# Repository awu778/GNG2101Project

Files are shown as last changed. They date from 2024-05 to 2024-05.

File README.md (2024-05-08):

# Helpo
This repository contains the design for the Helpo Keyboard. While there will be sales of the keyboard
in the future, this repository provides the files necessary for anyone to create a copy of the board for
personal use.
# Description
Photoshops landscape is large, confusing, and difficult to learn for disabled artists. Helpo is a photoshop assistant designed to increase the digital art app's accessibility through interactive tool select feedback, voice commands, and a physical tool keyboard. The project could be built for less than $40. Groups trying to replicate this project should watch out for the scope of the project; it's very easy to forget about one area when progress is being made in another. Possible steps forward include: improving the colour picker design while keeping it accessible (no colour cloud), adding the option for line smoothing, a cleaner integration into the photoshop interface, the ability to select specific brush sizes and colours from Helpo directly, and the ability to select favourite tools or brushes.

If you want to use this software, please download the Helpo_8.zip and Helpo.xml files. Unzip the .zip file and run the installer. To load up a profile, go to the top right, select load, and select the Helpo.xml file.

Made by Fall 2020 GNG 2101 - Accessible Digital Drawings Group A3. Made possible using GAVPI software.

## Terms of Use
Please refer to the LICENSE.md file in this repository for the terms of use. The purpose of sharing
the design is so others may create their own copy of the keyboard if they wish while also preventing
the commercial re-use of the design.

## Working with the Files
The following software is recommend to work with the Case/PCB design files.

* [Fusion 360](https://www.autodesk.com/products/fusion-360/overview)
* [KiCAD](https://kicad.org/)

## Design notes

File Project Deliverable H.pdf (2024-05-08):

## Project Deliverable H

-Economics Report-

Group A3

Austin Wu [300129117]
Benjamin Saulnier [300121338] Callum French [300128814]
Eleanor Rumsey [8274066]
Matthew Yakubu [300123797]

19/11/2020

GNG 2101 – Intro. to Product Dev. and Mgmt. for Engineers

Faculty of Engineering – University of Ottawa

# Table of Contents

Table of Contents | 2
Cost classification and estimation | 2
Table 1: Helpo Cost Classifications | 3
Table 2: Helpo Cost Justifications | 3
Income statements for three years | 4
Table 3: Income statement for Year 1 | 6
Table 4: Income statement for Year 2 | 7
Table 5: Income statement for Year 3 | 8
NPV analysis for break-even point | 9
Table 6: Cash flow for Year 1 | 9
Table 7: Cash Flow for Year 2 | 10
Table 8: Cash flow for Year 3 | 11
Analysis | 11
Assumptions | 12

# Cost classification and estimation

The following table shows a list of our companies cost, cos classification, and an estimation of an annual cost. A second table follows providing a justification for each of the costs.

Table 1: Helpo Cost Classifications

Cost Description | Cost Type | Amount (yearly)
Production Materials | Material, Variable, Direct | $10 per keyboard
Manufacturing | Labour, Semi-Variable, Direct | $86,400
Shipping | Expense, Semi-Variable, Direct | $10 per keyboard
Salaries | Labour, Fixed, Direct | $126,240
Overhead | Expenses, Fixed, Indirect | $1500
Rent | Expenses, Fixed, Indirect | $10,800
Utilities | Expenses, Semi-Variable, Indirect | ~$3,600
Marketing | Expenses, Variable, Indirect | $1000
Research and Development | Expenses, Variable, Indirect | $500
Tax | Expenses, Variable, Taxation cost (other) | Variable

Table 2: Helpo Cost Justifications

Cost Description | Cost Justification
Production Materials | In bulk, materials for each keyboard come out to roughly $10 each
Manufacturing | 3 employees working $15 an hour, 40 hours a week, 48 weeks a year
Shipping | Estimating high for around the world shipping, ~$10 per board
Salaries | 2 full time IT support and dev team working $25 an hour, 40 hours a week, 48 weeks a year ($96,000) and 3 interns working $14 an hour, 15 hours a week, 48 weeks a year ($30,240)
Overhead | Rough estimate for office supplies. In first year add $5000 for startup costs (printer, computer, soldering iron, etc)

Manufacturing costs are one of two main areas of focus for Helpo, Inc. Part of our product is the construction of a keyboard that a customer can take, customize, and use when creating their artwork. There are standard costs associated with this, including the cost of production materials to make PCBs, the manufacturing cost of assembling the PCBs, the rent for whatever factory these are being built in, their utilities, their overhead costs, their tax costs, and their shipping costs. One of the main differences between current design and one for mass production is the differentiation between through hole and surface mount. The PCB would be redesigned to be surface mount reducing the cost of assembly labour and the overall cost of components. As a small business, we are not partnering to sell this through a larger distributor like Best-Buy or Walmart, but are instead going to be in charge of our own shipping costs.
The other main area of focus for our product is the tech side; the voice activation system and UI. To keep these running, have customer support available, and continue improving, there are some costs. Included in this is IT salaries, rent for this building, their own overhead and utilities, and their own tax. Additionally, this group would also work with marketing and with research and development to continue to push the product out there and continue to improve it. Our business plan is not necessarily to make money, but instead to improve the lives of the disabled artists who our product can benefit. Because of this, even after considering all of these factors, the product would not be priced any higher than it has to be for us to break even. A small margin (within $20,000) would be considered acceptable for the company’s profit. This could be used as an emergency fund, and would be an indication that we could invest in more resources or reduce customer prices.

# Income statements for three years

Table 3, Table 4, and Table 5 display the income statements for Helpo’s first 3 years of operation.Values for bank loans, interest, and tax have not been included here; these are to gain an understanding of operational expenses primarily. The following assumptions have been made for these income statements:
1. The 3-year period examined here is 2020, 2021, 2022
2. The material cost of the keyboards remained the same for all 3 years, at $10/keyboard.
Rent | As a small company, we can rent cheaper. $900 a month
Utilities | Smaller building = less utilities but manufacturing = more electricity. Rough estimate $300 a month
Marketing | Small company focused on youtube advertisements, not mainstream media and posters. This is extremely variable
Research and Development | This is a budget the full time team has to spend on technology or rights to improve the software. Very variable and bound to increase.
Tax | Variable based on the company's final income. Should be low due to our “barely break even” mentality to try and keep costs low.

3. The cost of shipping for each keyboard is $15, and will be recorded in the “Shipping Expense” section.
4. The software license for Helpo was consistently priced at a one-time fee of $10/user.
5. Helpo, Inc. does not want to make any significant profit on the product, thus each income statement should produce only a small net income.
a. An acceptable range of profit is $20,000 to account for any emergencies or unforeseen costs
6. Assume that the expenses for Overhead, Rent, Utilities, Marketing, and Research and Development remain the same for each year.

In Year 1, Helpo Inc. sold 3000 keyboards at $35 each and 5000 user licenses. As a newly founded company it had a very small staff and so salaries were only $60,000. Manufacturing was done by one hourly employee, for a total cost of $28,800. In this first year, Helpo’s net income was negative, which is common in early years of start-ups.
In Year 2, Helpo sold 6000 keyboards and 10,000 user licenses. To help with the loss from Year 1, the price of each keyboard was increased to $40. Staff size increased as well, which was reflected in a Salaries expense of $90,000. Another manufacturing worker was hired due to the increased production demand, which brought manufacturing costs to $57,600.
In Year 3, Helpo sold 8,000 keyboards and 11,000 user licenses. The keyboard price was maintained at $40. Considering the profit of the previous year and the increased demand, staff size was increased to accommodate 3 interns, resulting in a total cost of $126,240 for Salaries. A third manufacturing worker was hired, resulting in a total cost of $86,400 for Manufacturing. The Net Income this year was -$40, which is almost a perfect break-even. By selling a few more keyboards, Helpo would directly meet its goal of providing quality products to the client with negligible personal profit. The exact number to break even will be examined in the NPV analysis for break-even point (next section).

Table 3: Income statement for Year 1

Helpo Inc.
Income statement
For the year ending December 31, 2020

Revenues

Sales | $155,000
Cost of goods sold | $30,000
Gross profit on sales | $125,000

Expenses

Operating Expenses

Shipping Expense | $45,000
Salaries Expense | $60,000
Manufacturing Expense | $28,800
Rent Expense | $10,800
Utilities Expense | $3,600
Overhead Expense | $1,500
Marketing Expense | $1,000
Research and Development Expense | $500

Total operating expenses
| $151,200
Operating income | $(26,200)
Net Income | $(26,200)

Table 4: Income statement for Year 2

Helpo Inc.
Income statement
For the year ending December 31, 2021

Revenues

Sales | $340,000
Cost of goods sold | $60,000
Gross profit on sales | $280,000

Expenses

Operating Expenses

Shipping Expense | $90,000
Salaries Expense | $90,000
Manufacturing Expense | $57,600
Rent Expense | $10,800
Utilities Expense | $3,600
Overhead Expense | $1,500
Marketing Expense | $1,000
Research and Development Expense | $500
Total operating expenses | $255,000
Operating income | $25,000)
Net Income | $25,000

Table 5: Income statement for Year 3

Helpo Inc.
Income statement
For the year ending December 31, 2022

Revenues

Sales | $430,000
Cost of goods sold | $80,000
Gross profit on sales | $350,000

Expenses

Operating Expenses

Shipping Expenses | $120,000
Salaries Expense | $126,240
Manufacturing Expense | $86,400
Rent Expense | $10,800
Utilities Expense | $3,600
Overhead Expense | $1,500
Marketing Expense | $1,000
Research and Development Expense | $500
Total operating expenses | $350,040
Operating income | $(40)
Net Income | $(40)

# NPV analysis for break-even point

The information for the cash flows shown in Tables 6, 7, and 8 is taken from the income statements for Year 1, Year 2, and Year 3.

Year 1
PV = (-26 000)/(1+0.0545)

1 = -$24,656.24

Year 2
PV = (25 000)/(1 + 0.0545)

2 = $22,482.62

Year 3:
PV = (-40)/(1+ 0.0545)

3 = -$34.11

NPV = -$24,656.24 + $22,482.62 - $34.11 - $100 = -$2,307.73

Year | Future Value | Factor | Present Value
| A | B | A/B
0 | | | (100)
1 | -$26,000 | (1 + 0.0545) | -$24,656.24
2 | $25,000 | (1 + 0.0545) 2 | $22,482.62
3 | -$40 | (1 + 0.0545) 3 | -$34.11
Net Present Value | -$2,307.73

Table 6: Cash flow for Year 1

Helpo Inc.
Cash Flow
For the year ending December 31, 2020
Cash In | Cash Out
Sales | $155,000 | Salaries | $60,000
| | Shipping | $45,000
| | Costs of Goods Sold | $30,000
| | Manufacturing | $28,800

Break-Even point (units) = Fixed Costs ÷ (Sales price per unit – Variable costs per unit)
$181 200 ÷ ($45 - $35) = 18 120 units
| Rent | $10,000
| Utilities | $3,600
| Overhead | $1,500
| Marketing | $1,000
| R & D | $500
Total Cash In | $155,000 | Total Cash Out | $181 200

Net Cash Flow = (total cash in - total cash out) = $155,000 - $181,200 = -$26,200

Table 7: Cash Flow for Year 2

Helpo Inc.
Cash Flow
For the year ending December 31, 2021
Cash In | Cash Out
Sales | $340,000 | Salaries | $90,000
| | Shipping | $90,000
| | Costs of Goods Sold | $60,000
| | Manufacturing | $57,600
| | Rent | $10,800
| | Utilities | $3,600
| | Overhead | $1,500
| | Marketing | $1,000
| | R & D | $500
Total Cash In | $340,000 | Total Cash Out | $315,000

Net Cash Flow = $340,000 - $315,000 = $25 000

Break-Even point (units) = Fixed Costs ÷ (Sales price per unit – Variable costs per unit)
$315 000 ÷ ($55 - $35) = 15 750 units

Break-Even point (units) = Fixed Costs ÷ (Sales price per unit – Variable costs per unit)
$430 040 ÷ ($55 - $35) = 21 502 units

# Analysis

Before starting this analysis, it's important to note that, as a company, we are focusing on "barely breaking even". Our goal is to provide a greater social benefit and just make enough profit to continue running. With that in mind, currently speaking, our social bottom line is extremely positive, but our fiscal bottom line is in the red. Performing an NPV analysis exaggerates this negative value even more as we can see that some changes would have to be

Table 8: Cash flow for Year 3

Helpo Inc.
Cash Flow
For the year ending December 31, 2022
Cash In | Cash Out
Sales | $430,000 | Salaries | $126,240
| | Shipping | $120,000
| | Costs of Goods Sold | $80,000
| | Manufacturing | $86,400
| | Rent | $10,800
| | Utilities | $3,600
| | Overhead | $1,500
| | Marketing | $1,000
| | R & D | $500
Total Cash In | $430,000 | Total Cash Out | $430,040

Net Cash Flow = $430,000 - $430,040 = -$40 made before launching this project. This could be done through the increase of prices, cutting back on personnel, or trying to reach a larger market. Another option would involve diversifying. Our logo is a very cute animal that could easily be marketbale. If we were to offer this as a stuffed animal, some shirts or hoodies, etc... and sell Helpo merchandise through a sustainably sourced clothing company, we can both raise publicity and profit. Additionally, we could partner with charities supporting disabled artists by giving them 50% of the income generated off of any merchandise sales. This would boost our financial profit, our social profit, and our environmental profit. Moving forward before fully launching this project, it would definitely be worth analyzing other options to ensure that we can keep an entirely green triple bottom line.

# Assumptions

To begin we must assume that customers have already purchased licencing for Adobe Photoshop. This makes a 1-time purchase option more financially feasible than a subscription for most users since they will already have a monthly subscription due for Adobe. This software will collect the interest of a wide range of users including many beginners since Photoshop can be an overwhelming software to learn. The beginner users may not use our product for an extended period of time therefore the subscription model once again becomes a less profitable solution for us. The users that will use our product for an extended period of time will be those with disabilities preventing them from using Photoshops basic software, this is a much smaller group of individuals which will most likely not cover all operating costs if they are paying for a monthly subscription alone.
For the sake of calculating the Net Present Value (NPV), we will assume that the interest rate is 5.45%. This represents Canada’s current prime interest rate, 2.45%, plus 3%.

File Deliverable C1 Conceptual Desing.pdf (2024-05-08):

## Project Deliverable C

Conceptual Design, Project Plan, and Feasibility Study

## Parts C1 and C2: Conceptual Design and Project Plan

Group A3

Austin Wu [300129117]
Benjamin (Ben) Saulnier [300121338] Callum French [300128814]
Eleanor (Ellie) Rumsey [8274066] Matthew (Matt) Yakubu [300123797]

01/10/2020

GNG 2101 – Intro. to Product Dev. and Mgmt. for Engineers

Faculty of Engineering – University of Ottawa

## Table of Contents

Table of Contents | 2
C.1 Conceptual Design | 3
Core functionality | 3
Problem Statement | 3
List of required product functions and sub-functions | 3
Task breakdown | 4
Figure 1: Functional decomposition chart | 4
Product concepts | 5
Table 1: Product concepts generated by the project team, three per member 5
Analysis and evaluation of concepts | 6
Analysis based on metrics | 6
Table 2: Target specifications from Deliverable B | 6
Table 3: Metric analysis of all product concepts | 7
Plus/minus analysis with base concept | 8
Table 4: Concept ranking (sum of weighted scores) | 8
Methods used for evaluation | 8
Choice of promising solutions | 9
Ellie - Concept 1 | 9
Ben - Concept 2 | 9
Matt - Concept 1 and Callum - Concept 1 | 9
Austin - Concept 1 | 9
Ellie - Concept 2 | 9
Matt - Concept 3 | 9
High-value features from chosen concepts | 9
Selected features for concept design | 10
Simplification of Photoshop UI | 10
Integration with Wacom tablet | 10
Command and gesture history and repetition | 10
Help system | 11
Tactile buttons | 11
Line smoothing | 11
Decision on group design concept | 11
Ideal product | 11
Feasible product | 12
Product concept conclusion | 12
Visual representation of design concept | 13
Figure 2: Visual representation of design concept | 13
Concept as related to target specifications | 14
C.2 Project Plan | 15
Figure 3: The detailed project timeline breakdown for group A3’s Accessible
Digital Drawings | 15

# C.1 Conceptual Design

## Core functionality

### Problem Statement

Photoshop has a cluttered and unfriendly interface that is especially challenging for our client, Madison, who has a fluctuating disability that occasionally affects their physical and neurological ability. An ideal solution would allow the Madison to continue to use Photoshop or other digital drawing tools, but provide additional functionality that would simplify the interface and allow multiple options for input, including voice, drawing tablet, and/or keyboard input.

### List of required product functions and sub-functions

The following list of functions provides high-level goals of our system, broken down into smaller sub-functions. These goals were determined based on the client needs and problem statement as well as target specifications (from Deliverable B). Higher functions are seen as each number, the letters underneath are sub-functions to complete the higher function, and the roman numerals are sub-sub-systems to ensure that the client will have the best possible experience.

1. Unclutter Photoshop interface and make it more friendly for Madii
a. Larger icons
b. Improved color picker
i. Different from normal gradient or wheel HSV/RGB selector (Madii finds it difficult to differentiate colors in these)
c. Improved brush selection
i. Organise list of available brushes
ii. Highlight frequently used brushes
d. Simpler UI for finding commands and tools in menus
e. Help functionality
i. Tutorials
ii. | Tooltips in-app
iii. | Search for commands
f. Drawing guides for shaky hands
i. Line smoothing
ii. Shape creation
g. Command history
i. Command repetition
2. Allow various input sources to accommodate for Madii’s disability
a. Voice commands
i. Voice Navigation

ii. Vocal drawing aid
b. Drawing tablet & pen
i. Can be used as a mouse
c. Keyboard input
3. Avoid possible triggers for Madii’s disability
a. No red colours in interface
b. No fast pop-ups or animations

### Task breakdown

The following diagram is a functional decomposition flowchart, showing basic task breakdown.

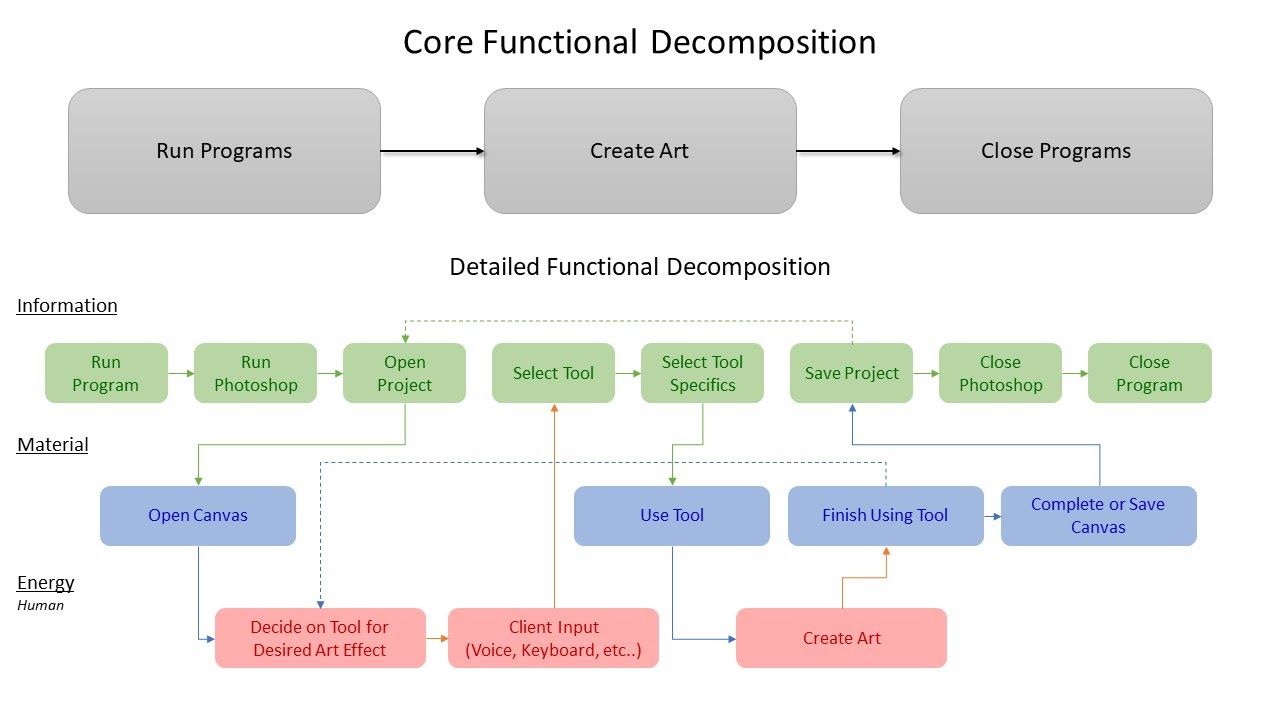
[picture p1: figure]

Figure 1: Functional decomposition chart

## Product concepts

The following concepts were generated from the team members as potential solutions to the problem statement.

Table 1: Product concepts generated by the project team, three per member

| 1 | 2 | 3
Austin | An external custom keyboard that allows for rebinding of keys and hotkey functions for photoshop | Tool integrated into wacom tablet that allows for easy switching between tools, rapid copy pasting capabilities | New UI that allows for simplifying down the menus in photoshop
Ben | A more accessible UI over Procreate to allow user to work under many circumstances | An ergonomic pen for the wacom tablet, allowing user to hold pen more comfortably | A plug-and-play accessible keyboard that comes with accessible design software
Callum | A voice input program that will select small icons and help navigate challenging menus | A new UI to place over Photoshop, simplifying the UI | A series of easy-to-access quick “help” videos to walk clients through the complexity of photoshop, built in.
Ellie | A toolbar UI that can be used with Photoshop (or other tools) with basic commands that can be activated by mouse, keyboard, or voice | A UI that focuses specifically on aspects of the Photoshop UI that the client felt overwhelmed by - e.g. color picker, brush size | A tool integrated into the Wacom tablet that uses gesture commands for tools such as fast copy/paste, line smoothing
Matt | A voice command system that makes it sufficient to complete simple drawing processes for any possible art concepts. | A simplistic UI that will be designed to make navigation easier while using Photoshop | A modification to the wacom tablet that stores the most common drawing patterns read by the tablet.

## Analysis and evaluation of concepts

### Analysis based on metrics

In Deliverable B, nine metrics were established to evaluate solutions. These same metrics have been added here and will be used to evaluate the solutions from Table 1.

Table 2: Target specifications from Deliverable B

| Metric | Units | Ideal | Acceptable
1 | UX as empathetic with client | Personal ranking | 5 | 4-5
2 | Number of repeatable functions | Positive integer (count) | 100 | 20-100
3 | Icon size | px or cm (on-screen) | 50px/2.5cm | 35-100px/ 1.4-3.0cm
4 | Customizability | Personal ranking | 5 | 3-5
5 | Number of commands recorded | Positive integer (count) | 100 | 50-100
6 | Assistive features | Personal ranking | 5 | 5
7 | Prevalence of red | % on startup | 0% | <10%
8 | Presence of fast pop-ups | Yes/No | No | No
9 | Hardware Integrability | Personal Ranking | 5 | 5

The metrics in Table 2 were used to evaluate all fifteen proposed concepts seen in Table 1. The results of this evaluation are shown below in Table 3.

Table 3: Metric analysis of all product concepts

| Concept | Metric (cross-reference to Table 2)
1 | 2 | 3 | 4 | 5 | 6 | 7 | 8 | 9
Austin | 1 | 3 | 100 | 1.4cm | 5 | 100 | 3 | 0% | No | 5
| 2 | 4 | >10 | N/A | 4 | N/A | 2 | 0% | No | 5
| 3 | 5 | N/A | 50px | 3 | N/A | 4 | 0% | No | N/A
Ben | 1 | 4 | 100 | 50px | 2 | 1 | 4 | 0% | No | N/A
| 2 | 3 | N/A | N/A | 5 | >10 | 3 | 0% | No | 4
| 3 | 5 | 100 | 50px | 4 | 100 | 5 | 0% | No | 5
Callum | 1 | 3 | N/A | N/A | 3 | 100 | 4 | 0% | No | 3
| 2 | 5 | N/A | 50px | 4 | N/A | 4 | 0% | No | 5
| 3 | 2 | N/A | N/A | 1 | N/A | 3 | <10% | No | N/A
Ellie | 1 | 5 | 100 | 50px | 5 | 100 | 5 | 0% | No | 5
| 2 | 5 | 50 | 50px | 4 | 100 | 4 | 0% | No | N/A
| 3 | 4 | 20 | N/A | 2 | 10 | 4 | 0% | No | 5
Matt | 1 | 5 | 20 | N/A | 3 | 20 | 4 | 0% | No | 4
| 2 | 4 | N/A | 50px | 4 | N/A | 4 | 0% | No | 5
| 3 | 5 | 10 | N/A | 5 | 10 | 4 | 0% | No | 5

Notes:
1. Any features, such as those relating to the UI, are given the ideal metric value because they can be built to meet these specifications
2. Top priority metrics, such as prevalence of red and fast pop-ups, were specifically avoided by all team members during concept generation
3. Yellowed boxes indicate successfully reaching the target values, and was used to visualize how successful a possible solution could be

### Plus/minus analysis with base concept

An idea that was common to more than one concept was a simplified UI for Photoshop. This idea was taken as the reference for a sum of weighted scores comparison in the following table.

Table 4: Concept ranking (sum of weighted scores)

| Concepts to compare
Metric | Simplified Photoshop UI (Reference) | Austin | Ben | Callum | Ellie | Matt
1 | 2 | 3 | 1 | 2 | 3 | 1 | 2 | 3 | 1 | 2 | 3 | 1 | 2 | 3
1 | 0 | - | + | 0 | 0 | 0 | 0 | + | 0 | - | + | + | 0 | + | 0 | -
2 | 0 | - | - | 0 | 0 | - | - | 0 | 0 | - | 0 | - | - | - | 0 | 0
3 | 0 | 0 | 0 | 0 | 0 | - | 0 | - | 0 | - | 0 | 0 | - | - | 0 | -
4 | 0 | 0 | - | 0 | 0 | - | - | - | 0 | - | 0 | - | - | 0 | 0 | 0
5 | 0 | - | 0 | 0 | 0 | - | - | - | 0 | - | 0 | - | - | - | 0 | 0
6 | 0 | - | 0 | 0 | 0 | + | 0 | + | 0 | 0 | + | 0 | + | + | 0 | +
7 | 0 | 0 | 0 | 0 | 0 | 0 | 0 | 0 | 0 | - | 0 | 0 | 0 | 0 | 0 | 0
8 | 0 | + | 0 | 0 | 0 | 0 | 0 | 0 | 0 | 0 | 0 | 0 | 0 | 0 | 0 | 0
9 | 0 | 0 | 0 | 0 | - | + | + | 0 | 0 | - | + | 0 | 0 | 0 | 0 | 0
Total | 0 | -3 | -1 | 0 | -1 | -2 | -2 | -1 | 0 | -7 | 3 | -2 | -3 | -2 | 0 | -1

### Methods used for evaluation

These evaluations were done during a team meeting with all group members. Group consensus was used for decision-making, with a focus on client empathy. Ideas were compared against each other using both quantitative and qualitative measures of the value they provided to the client as well as some basic feasibility discussion (e.g. would a concept be easy to collaborate on remotely).

## Choice of promising solutions

Promising solutions were selected based on scoring from the above analyses as well as by unique features that deserved to be given attention. The following six concepts were selected for further analysis:

Ellie - Concept 1
A toolbar UI that can be used with Photoshop (or other tools) with basic commands that can be activated by mouse, keyboard, or voice.

Ben - Concept 2
An ergonomic pen for the wacom tablet, that allows the user to hold the pen more comfortably.

Matt - Concept 1 and Callum - Concept 1
These two concepts were almost identical and thus will be treated as one. This is a voice command-based system that facilitates clicking small icons, navigating menus, and other simple processes in Photoshop.

Austin - Concept 1
An external custom keyboard that allows for rebinding of keys and hotkey functions for Photoshop.

Ellie - Concept 2
A UI that focuses specifically on simplifying aspects of the Photoshop UI that the client felt overwhelmed by, such as the color picker and brush properties.

Matt - Concept 3
An addition to the wacom tablet that stores the most common drawing patterns and gestures performed on the tablet.

### High-value features from chosen concepts

Features that provided the most value to the client were extracted from the chosen concepts and some additional ideas and details were added through discussion. They are listed as follows with brief descriptions:

1. Simplification of Photoshop menus, icons, and tools
a. Specifically mentioned by client as strong need
2. Simplification and redesign of the brush properties tool and color picker
a. Specifically mentioned by client as strong need
3. Improvement of Wacom pen a. Client mentioned pain in hand when using normal Wacom pen
b. A hardware concept the client is already familiar with; easily integrable
4. Re-creation of simple art processes using voice commands, e.g. “draw circle”
a. Client is currently unable to use Photoshop when they don’t have control of their hands
5. Voice commands for menu navigation, tool selection
a. Client is currently unable to use Photoshop when they don’t have control of their hands
6. Tactile buttons or external keyboard to control Photoshop
a. Easier to manipulate than a mouse
b. Buttons provide a larger interface than Photoshop icons
7. Gesture and command repetition
a. Saves effort for the client
8. Line smoothing
a. Mentioned by the client as a specific need
9. Physical or on-screen drawing guides
a. Client currently draws with two hands; they rest one on their tablet in order to guide their lines

### Selected features for concept design

From the discussion of high-value features, the team then narrowed down the desired concept features to the following five ideas:

Simplification of Photoshop UI
This would involve making the menus, icons, and tools in Photoshop easier for the client to navigate and use. All icons would need to be larger and tools that the client does not use would be hidden. Improvements would also be made to the brush selection tool and color picker. Voice activation could also be implemented here.

Integration with Wacom tablet
As the Wacom tablet is the tool that the client currently uses to create their art, it would be ideal to allow them to keep using it with the new product. The tablet functions as a mouse as well, so its integration could be limited to that, or options with the buttons and pen could be explored.

Command and gesture history and repetition
This would include the ability to recreate frequently used processes by recording their use history in the system. Voice activation could also be used here.

Help system
The client feels overwhelmed by the options available in Photoshop. The proposed solution will make their interaction with the program simpler but also more limited. A friendly help system would help build the client’s confidence with Photoshop’s tools alongside the solution.

Tactile buttons
The client may not always be able to manipulate a cursor on a screen, in which case large, tactile buttons would be a useful feature.

Line smoothing
The client has complained about their drawn lines being shaky if their hands are unstable. Adding line smoothing functionality to the solution would add value in these situations.

## Decision on group design concept

### Ideal product

An ideal solution to the client’s needs would allow them to create art using any form of input; voice, gesture, tablet, keyboard, or mouse. This system would be uniquely adapted to fit their needs at any given time and provide an easy to use interface, being able to switch between any input form at any time. Art creation could be a whole body process using large gestures, or require as little movement as just talking. It would record frequently used gestures and commands and could be requested to repeat these either through the UI or by any of the aforementioned input methods. At any point while using this system, the client would be able to request assistance with the commands, tools, or system in general. This ideal solution would be comparable to Tony Stark’s assistant Jarvis from the Iron Man movies (pictured below).

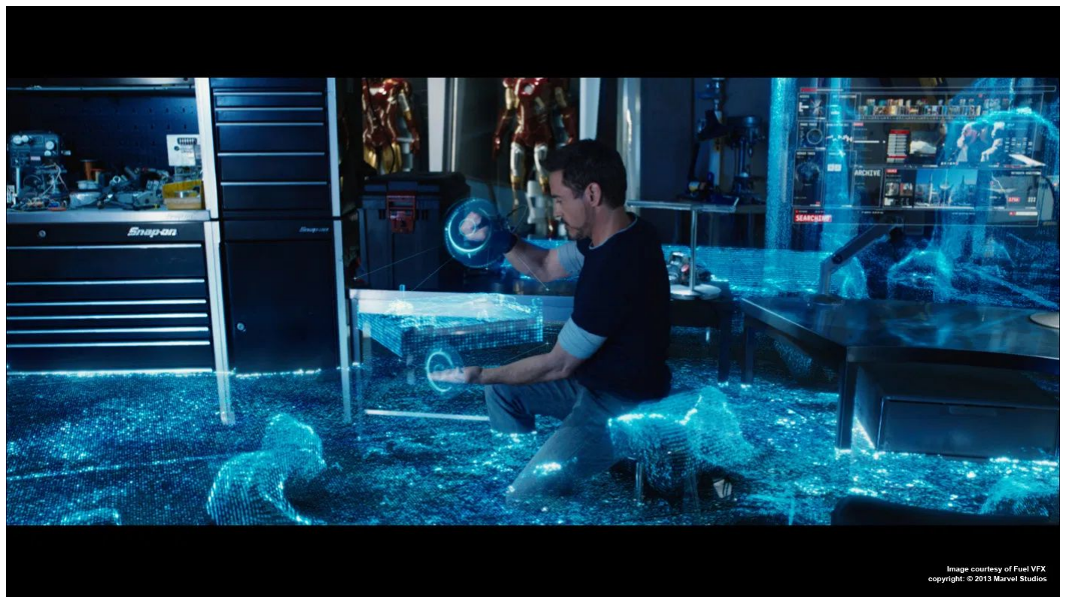
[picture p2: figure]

(image credit: https://www.artofvfx.com/iron-man-3-paul-butterworth-simon-maddison-vfx-supervisors-fuel-vfx/)

Unfortunately, the scope and resources required to create such a system are beyond those available to the team at the moment. A more realistic concept must be designed, that can still meet client needs.

### Feasible product

It is important that the system can be used with whatever abilities Madi has at a given time. Voice input as a feature is more of a priority than creating an external keyboard or button system as the client already is using an environment they can manipulate with their hands and has expressed issues with that approach. As well, a software rather than hardware solution would be cheaper, involve less setup for the client, eliminate the need for shipping and delivery (especially with COVID-19) and facilitate remote team collaboration.
The UI of this system needs to be simpler than what Photoshop currently has, and provide improvements specifically in icon size, color picker, brush selection, and menu navigation. A history function will also be a valuable feature, allowing the client to repeat recently and frequently used commands and/or gestures.Ideally the UI should be intuitive enough to reduce the need for a full help system; however if time permits it would be valuable for the client to have introduction tutorials or a help database available.

### Product concept conclusion

Based on the above criteria, the solution for this project is an auxiliary interface that runs as a desktop application concurrently to Photoshop. This system can be controlled by voice, mouse, wacom tablet (as mouse), or keyboard. The UI should include large icons and simple menu navigation, color picking, and brush selection. These tools are all tied to the corresponding Photoshop tools. Functionality of the system also includes a record of command history that can be repeated.
The following tools have been chosen as the most likely to be used by our client in Photoshop, and should be included in the concept development for the system: mouse pointer, paint brush and brush selection panel, eraser, paint bucket, text, lasso/rectangle select, layer manipulation, zoom, and color select.

## Visual representation of design concept

The following is a possible UI for the system, and will provide the basis for rough prototyping.

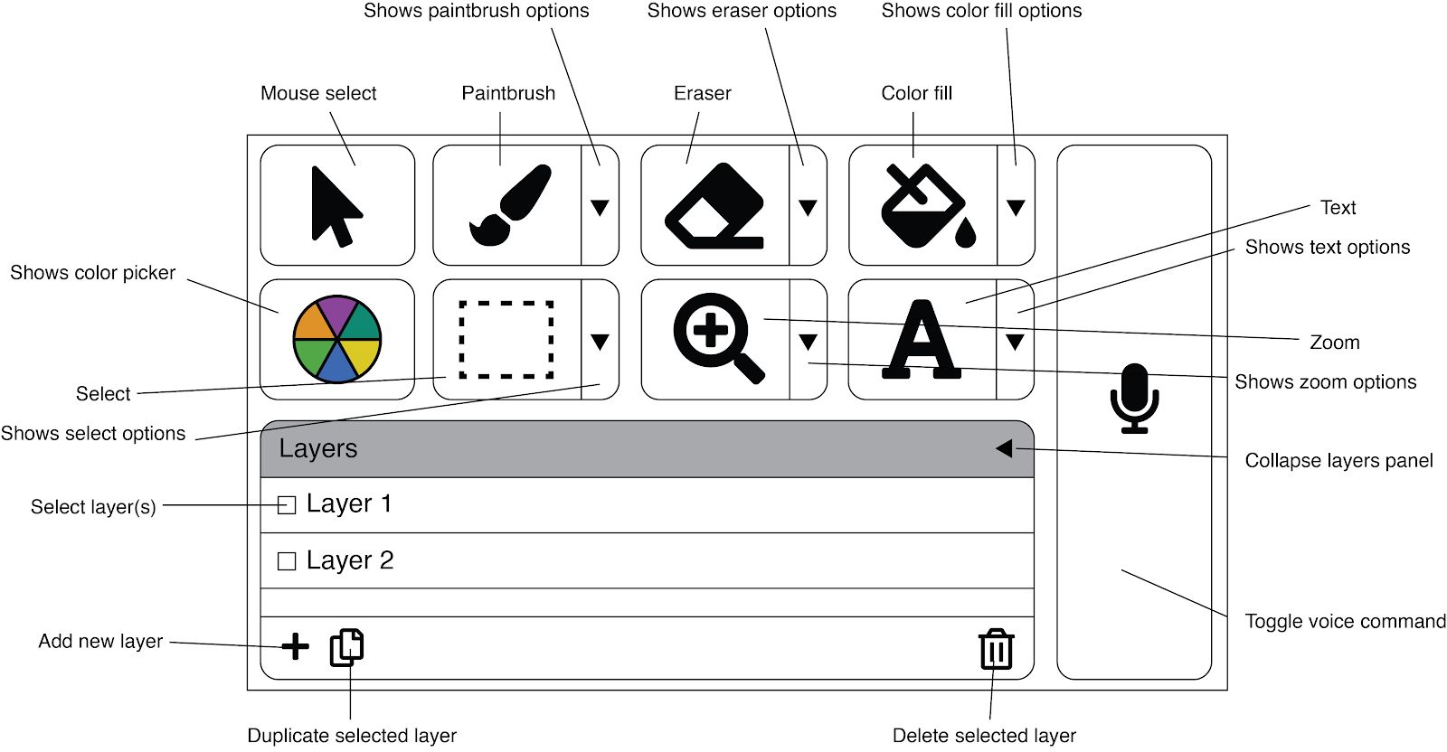
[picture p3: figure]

Figure 2: Visual representation of design concept

## Concept as related to target specifications

Our project concept will meet the aesthetic target specifications such as the absence of red, no fast pop-up windows as well as larger icons. These specifications were our top priority because they directly impact Madison’s disability and have been known to trigger it at times.
The specifications that are related to accessibility were important to us because we want Madi to be able to use our product whenever they need it, no matter the obstacles they may be facing at that particular time. Madi’s fluctuating disability meant that a couple different solutions may be required for the solution. Our software solution allows the user to use voice commands to complete simple tasks on days where hand functionality is low, as well as improve the UI because Photoshop can be difficult to navigate at times and become overwhelming. This may include a new task bar, larger icons and frequently used icons all to improve the way the client will interact with our program.
The hardware solution, if implemented in addition or as replacement to the software solution, would focus on comfort and simplicity. Considering a hardware solution is important as well because Madi discussed during the client interview about how current technology has not been working for them and they would like a better option to create art when using their hands. Some features of the hardware solution might include quick copy and paste, a line straightener, eraser, zoom, and more. Some drawbacks may include pricing as including a hardware component may become expensive and using a closed source software like Photoshop could prove to be a challenge to work with.

# C.2 Project Plan

An image of the Project Plan can be seen below. It will be updated as time goes on, especially breaking down tasks under each prototype to ensure that the group can present a complete product. Additionally, a PDF of the Project plan has been attached, which is higher definition.

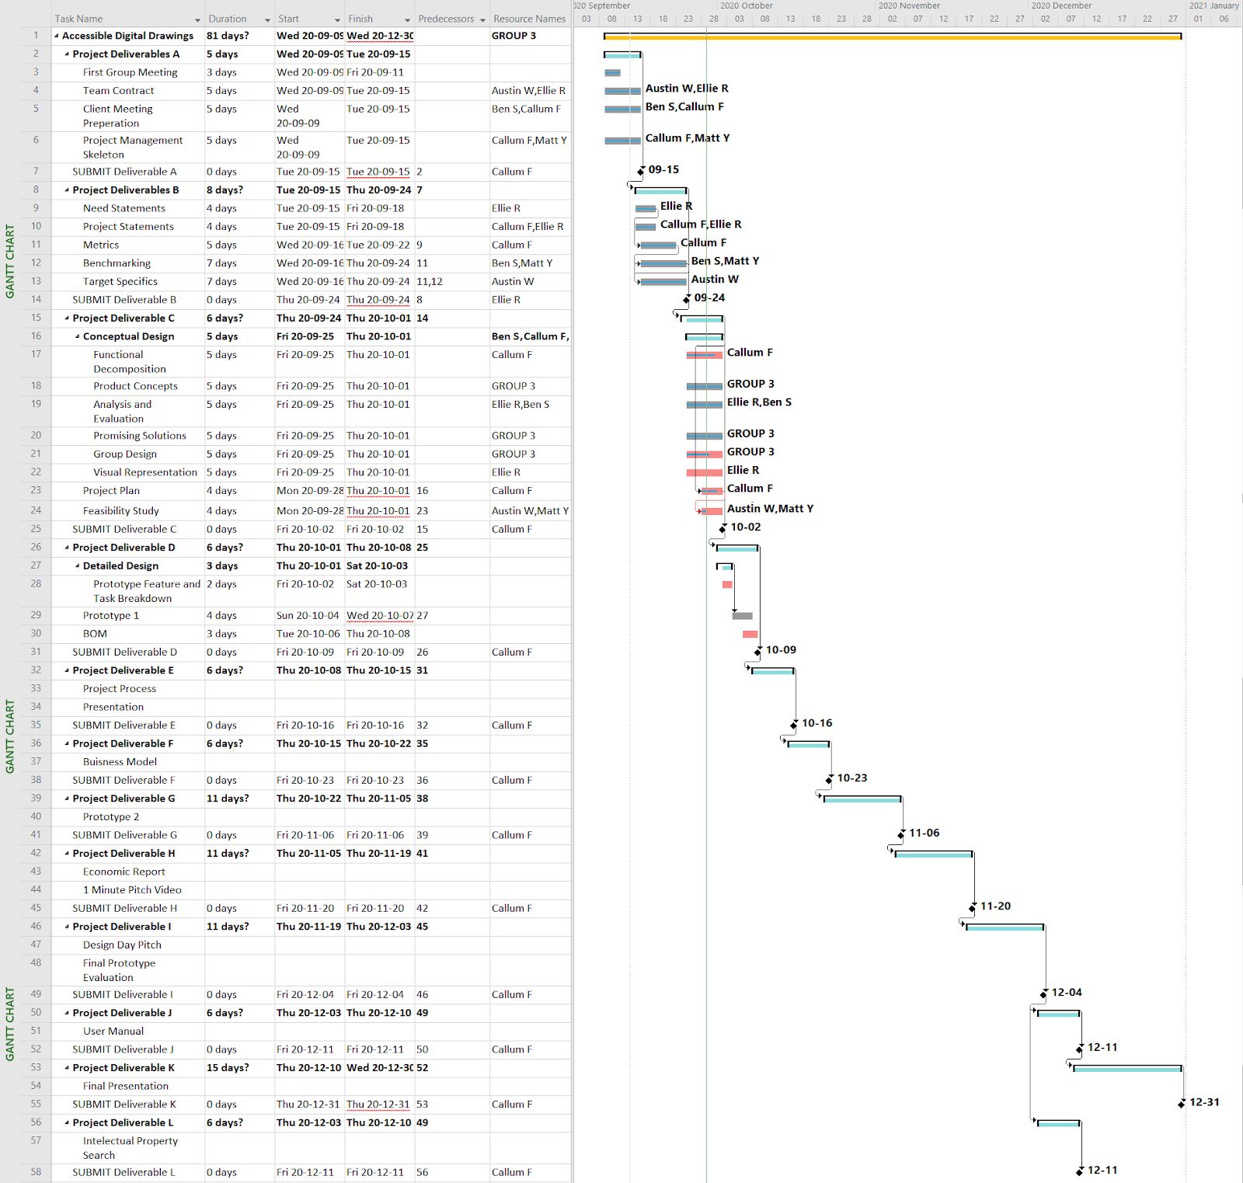
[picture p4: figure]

Figure 3: The detailed project timeline breakdown for group A3’s Accessible Digital Drawings

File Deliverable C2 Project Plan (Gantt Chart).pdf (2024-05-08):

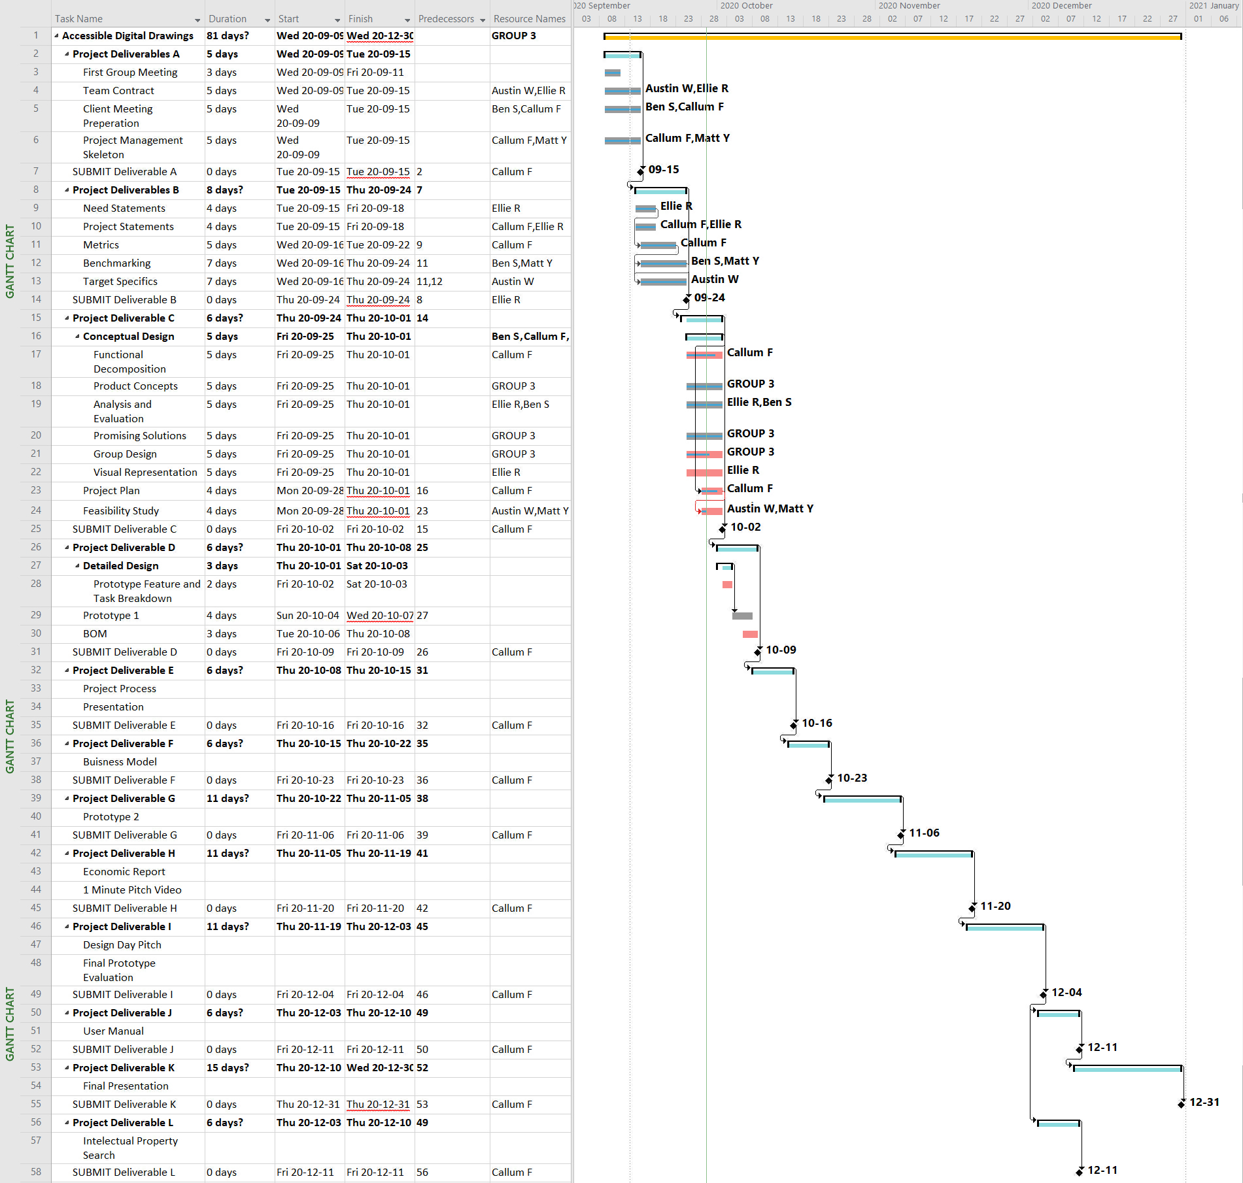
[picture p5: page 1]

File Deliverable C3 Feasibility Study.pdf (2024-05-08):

## Project Deliverable C

Conceptual Design, Project Plan, and Feasibility Study

## Part C3: Feasibility Study

Group A3

Austin Wu [300129117]
Benjamin Saulnier [300121338] Callum French [300128814]
Eleanor Rumsey [8274066]
Matthew Yakubu [300123797]

01/10/2020

GNG 2101 – Intro. to Product Dev. and Mgmt. for Engineers

Faculty of Engineering – University of Ottawa

## Table of Contents

Table of Contents | 2
Project concept | 3
Uncertainties and risks associated with the project | 3
Experience coding desktop applications | 3
Voice commands | 3
Keyboard mapping | 3
Feasibility study - TELOS factors | 4
Technical: Expertise and Resources | 4
Economic: Cost Benefit/Analysis | 4
Legal: Determination of Applicable Laws | 4
Operational: Organizable Constraints and ‘other’ Factors | 5
Schedule: Deadlines and Reasonability | 5

## Project concept

The solution for this project is an auxiliary interface that runs as a desktop application concurrently to Photoshop. This system can be controlled by voice, mouse, wacom tablet (as mouse), or keyboard. The UI should include large icons and simple menu navigation, color picking, and brush selection. These tools are all tied to the corresponding Photoshop tools. Functionality of the system also includes a record of command history that can be repeated. (see section C1 - Decision on group design concept for details)

## Uncertainties and risks associated with the project

### Experience coding desktop applications

Of the five members of the project team, only one (Eleanor) has experience with building applications from scratch. Eleanor also does not have much experience building desktop applications. However, all members of the team have experience with coding in some capacity and feel confident that the code necessary to create the product will not be beyond the team’s collective skill level.

### Voice commands

A main feature of the product is its ability to be controlled by voice. However, voice command systems are notoriously unreliable and difficult to implement. The team has performed some research and intends to make use of voice command libraries and open-source tools that are available online. Decision of the best voice command tool will be done during the prototyping phase of the project, once other system specifications have been established.
It will be important to communicate with the client that the product’s voice command system, like any other, will not be one hundred percent reliable. As the client specifically mentioned the need for voice input during our initial interview, the value added by a voice command feature outweighs the risk that it is not perfect.

### Keyboard mapping

The concept at the moment involves simulating the keyboard shortcuts that are used to access tools in Photoshop. Austin has some experience with custom key-mapping with hardware and the team is confident that this can be achieved through JavaScript. As none of the team has experience simulating these key presses using software, there is a risk that this solution will be time consuming. However, it is the simplest solution that has been discussed, that involves the fewest changes to the client’s current work environment.

## Feasibility study - TELOS factors

### Technical: Expertise and Resources

For our chosen solution, Ellie’s experience with building UIs leaves her comfortable with using tools to build a new desktop software such as Electron to go with Photoshop. Callum can provide support with many steps as he has experience with HTML/CSS and JavaScript as well. The rest of the team members all have some experience with programming for smaller portions. This solution takes little to no resources other than selecting a framework and time coding in JavaScript. We also plan on implementing GAVPI or another voice command framework to improve the accessibility of our solution.

### Economic: Cost Benefit/Analysis

We will look for tools and frameworks on open-source sites to avoid recreating tools which would be difficult for our team’s level of experience and very time consuming. We have looked at existing solutions that try to add to the accessibility and ease of use of photoshop, however most of the items selected to be used for the benchmarking does not have the same specifications as we desired. Most of the items only have one or two similar features and that was taken into consideration when attempting to calculate the costs. Hardware solutions tend to be on the more expensive side compared to add on software. Some software that was used for benchmarking was also open source, reducing the costs for the consumer.
In terms of marketing, the primary event for showing off the project and its applications will be on design day. An additional opportunity that the group has though is to advertise through the client’s foundation; as they specialize in art therapy for disabled persons. If the client happens to like the solution then there is an avenue of advertising through the client’s foundation. Because there are no foreseeable financial costs related to our software, this “marketing” isn’t for the purpose of making money, but simply to spread the software and improve the lives of disabled artists. However, if we decide to include a hardware component then it is possible that we will have to reevaluate any additional costs required and the corresponding marketing strategies.

### Legal: Determination of Applicable Laws

Our client is currently using Adobe Photoshop for their digital art however, Adobe remains the exclusive owner of their services and software. Since photoshop is an Adobe product and remains closed source, the individual source code cannot be directly changed or edited in any way. The users do own any content that they create using Adobe software though, an important note for the artists. We must be careful and make sure that we are creating our own toolbar that assists with Photoshop rather than change Photoshop. Adobe expressively states in their legal code note number 17: “17. No Modifications, Reverse Engineering. Except as expressly permitted in the Terms, you may not (A) modify, port, adapt, or translate any portion of the Services or Software; or (B) reverse engineer (including but not limited to monitoring or tracking the inputs and outputs flowing through a system or an application in order to recreate that system), decompile, disassemble, or otherwise attempt to discover, within any Service or Software, the source code, data representations or underlying algorithms, processes, methods, and any other portion of such Service or Software”. In any solution the team creates, maintaining these legalities in the front of our minds will ensure that the product created does not infringe upon any applicable laws and will be able to be distributed legally.

### Operational: Organizable Constraints and ‘other’ Factors

Our team will face many constraints such as location, finances, prototypes, development speed, reliability on feedback, product life and ease of use. Because all team members are currently working from home due to COVID-19 restrictions, in-person team meetings and discussions are impossible, which can possibly decrease the speed of product development. Finances are currently not predicted to be an issue since we are focused on the software solution, however if we do decide to incorporate the hardware solutions that we came up with in any way the budget could pose as a constraint. The development speed could be slowed down as well due to personal schedules since every member of the team has strict schedules and will not always be able to work on deliverables at the same time. Team members will need to balance this course with their test, labs or other assignments from different classes and personal commitments. Reliability on feedback is another factor that could slow down the process of our project. Because none of us can truly experience what Madison is going through we will need to ask for feedback often to make sure our solution is still on the right track. Our client is also a student and will not always be available to provide feedback as soon as we request, which could create blocks in our development. The product life is a constraint that we have very little control over since the software that we are improving is not made by us. The team will most likely be unable to provide further updates to our product after the completion of the course, and so would be unable to adapt to any future versions of Photoshop.It is possible that if Adobe continues to update their product, our modifications could become outdated and that our final solution is only functional with the current version of Photoshop (2020). Finally the ease of use is a very important part of our solution but we have already seen that it is difficult to measure without directly observing the client testing our prototypes and therefore will be completely reliant on the user’s feedback.

### Schedule: Deadlines and Reasonability

Attached to this submission as a PDF document is a Gantt chart showing the proposed schedule for the completion of the project, as well as all related deadlines. Seeing as this is a class that has been run successfully for years, churning out helpful products, the timeline and deadlines are reasonable. To ensure the reasonableness of these deadlines though, the project scope has been toned down from the described “Ideal” solution (seen in part C1) to a more realistic and feasible one. If everything goes mostly as planned, a successful project will be able to be produced.

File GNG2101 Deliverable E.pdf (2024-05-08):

# Deliverable E: Project Progress Presentation

### Group 3: Accessible Digital Drawing

Eleanor Rumsey [8274066]
Callum French [300128814]
Austin Wu [300129117]
Matthew Yakubu [300123797] Benjamin Saulnier [300121338]

# Key components of project deliverables to date

# Team Contract

- Team Leadership: Informal
- As a group of 5, we can realistically come to any solution democratically and remain on schedule.
- Communication: Through Discord
- Voice, Video, text chat, file sharing, and notification all in one software.
- Meetings: Weekly
- Notes taken
- Member progress tracked in MS Project
- Meeting agenda focused by Eleanor
- Submissions: Weekly
- Callum responsible for weekly submissions on Thursday evenings

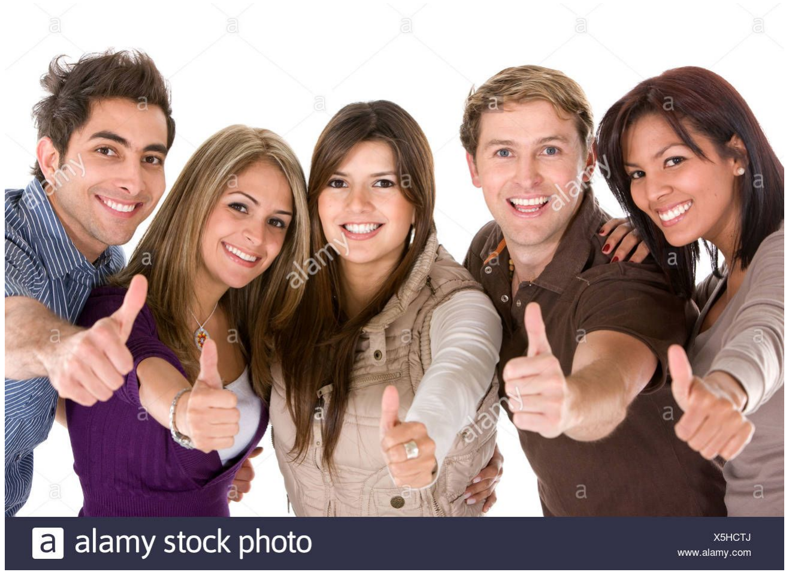
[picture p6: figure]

Contract Success
- Still Together
- Still Kicking
- Still Going Strong
- Still Supporting Each Other Through any Difficulties

## Deliverable A

# Client Summary: Madison Ward

Madii is an artist and student. They are non-binary and study Fine Arts at the University of Ottawa with the hopes of becoming a registered Art Therapist.

Their art is surrealist, and they use a variety of media. They describe their art as an “escape” and want to “invoke a reaction” from viewers. Much of their works has themes of struggling with mental health.

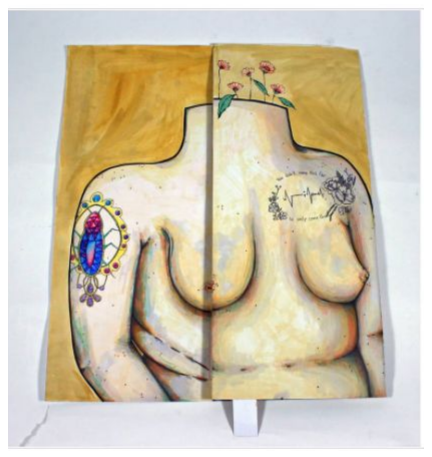
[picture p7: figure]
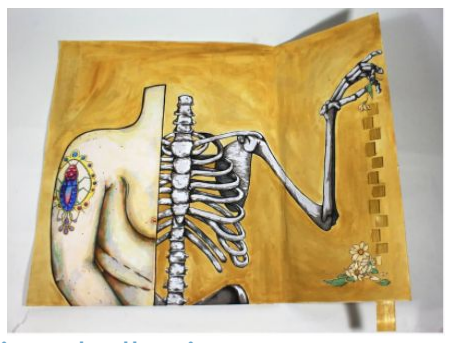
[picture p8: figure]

www.madiiwardcollective.ca

## Deliverable A

# Client Summary: Madison Ward

Madison has a fluctuating disability called Conversion Disorder or Functional Neurological Disorder.

The effects are vast and ever-changing. One day, Madii could be completely fine and the next, unable to move or talk. Anything can trigger these changes, from stress to the colour red.

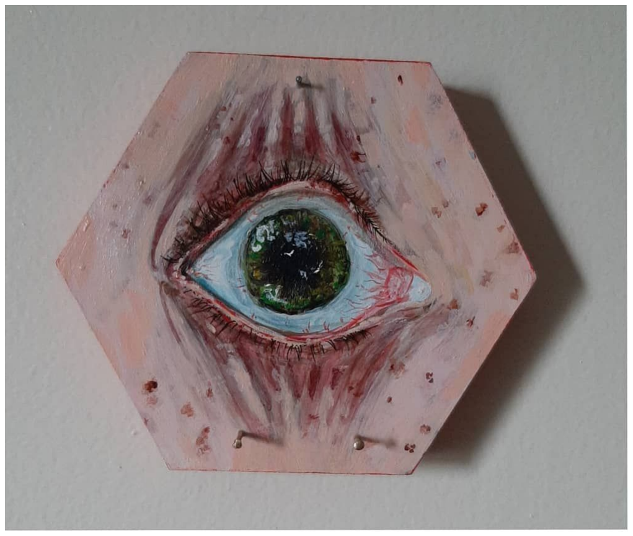
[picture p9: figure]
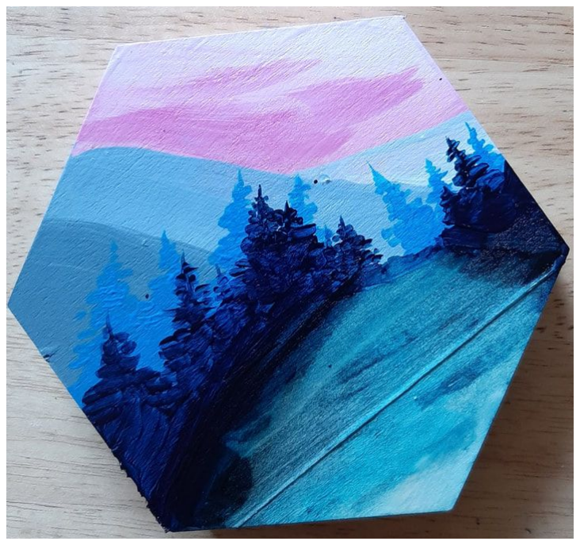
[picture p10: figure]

www.madiiwardcollective.ca

## Deliverable A

# What is our Project?

Project Name: Accessible Digital Drawings

Madii has struggled with bringing their art to the digital medium. Photoshop is too confusing, contains too many triggering features, and cannot be used every day.

Madii wants to have access to a digital art platform that is simple, accessible, and inspiring. They never want to feel like their disability is a block in their creative process, no matter the medium.

The project is designed to help Madii complete and sell their art in a digital landscape.

## Deliverable A

# | Need Statement | Priority 1 (low) to 5 (high)

1 | The software interface has a more comprehensible tool ribbon | 4
2 | The software has a method for easily repeatable functions | 3
3 | The software interface has large icons that are easy to find and distinguish from others | 4
4 | The software interface has minimal options shown | 3
5 | The system is able to recall and display previously and commonly used commands | 2
6 | The system is able to quickly copy and paste | 2
7 | The system can smoothen lines that are drawn shakily | 4
8 | The software interface allows selection between different line weights and patterns | 5

## Deliverable B

# Client Needs

Client | 9 | The system can be operated using voice commands | 4
| 10 | The system can be operated using a keyboard or buttons | 5
| 11 | The software interface does not have any red colors | 5
| 12 | The system allows the user to choose different colors without using the typical color-picker | 4
| 13 | The system inspires the user to create art despite any daily struggles with their disability | 5
| 14 | The software interface does not have any flickering or fast popup animations | 4
| 15 | The software is compatible with the client’s drawing tablet and a normal mouse and keyboard | 3

## Deliverable B

# Needs

# Problem Statement

Photoshop has a cluttered and unfriendly interface that is especially challenging for our client, Madison, who has a fluctuating disability that occasionally affects their physical and neurological ability. An ideal solution would allow the Madison to continue to use Photoshop or other digital drawing tools, but provide additional functionality that would simplify the interface and allow multiple options for input, including voice, drawing tablet, and/or keyboard input.

## Deliverable B

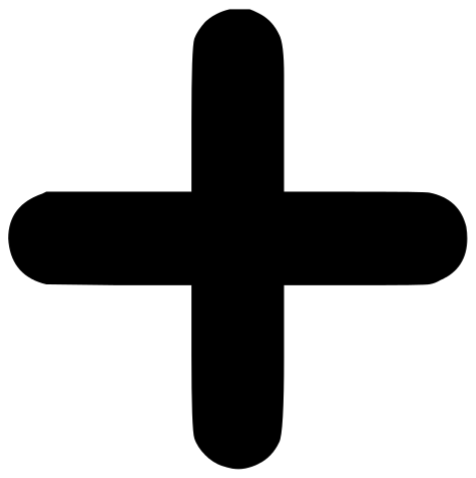
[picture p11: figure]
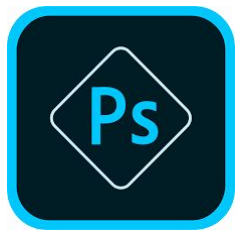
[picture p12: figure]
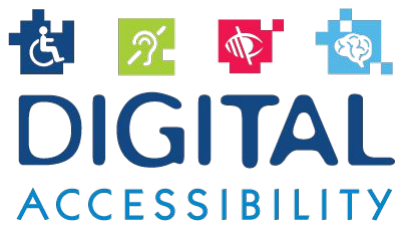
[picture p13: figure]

Target Specifications | | Metric | Units | Ideal | Acceptable
| UX as empathetic with client | | Personal ranking | 5 | 4-5
| Number of repeatable functions | | Positive integer (count) | 100 | 20-100
| Icon size | | px or cm (on-screen) | 50px/ 2.5cm | 35-100px/ 1.4-3.0cm
Customizability | Personal ranking | 5 | 3-5
Number of commands recorded | Positive integer (count) | 100 | 50-100
Assistive features | Personal ranking | 5 | 5
Prevalence of red | % on startup | 0% | <10%
Presence of fast pop-ups | Yes/No | No | No
Hardware Integrability | Personal Ranking | 5 | 4-5

## Deliverable B

# Benchmarking

Metric | Photoshop | Yanko keyboard | Procreate | GAVPI | Windows voice control
UX as empathetic with client | 2 | 1 | 5 | 2 | 2
Number of repeatable functions | >1000 | 29 | >100 | N/A | N/A
Icon size | 25px | 1.4cm | >1cm | N/A | N/A
Customizability | 2 | 1 | 1 | 5 | 2
Number of commands recorded | 0 | 0 | 1 | Infinite | 20
Assistive features | 2 | N/A | 1-2 | 5 | 4
Prevalence of red | >10% | 0% | 0% | >10% | 0%
Presence of fast pop-ups | No | No | Yes | No | No
Hardware Integrability | 5 | 5 | 3 | 4 | 4

## Deliverable B

# Concept Generation

| 1 | 2 | 3
Austin | An external custom keyboard that allows for rebinding of keys and hotkey functions for photoshop | Tool integrated into wacom tablet that allows for easy switching between tools, rapid copy pasting capabilities | New UI that allows for simplifying down the menus in photoshop
Ben | A more accessible UI over Procreate to allow user to work under many circumstances | An ergonomic pen for the wacom tablet, allowing user to hold pen more comfortably | A plug-and-play accessible keyboard that comes with accessible design software
Callum | A voice input program that will select small icons and help navigate challenging menus | A new UI to place over Photoshop, simplifying the UI | A series of easy-to-access quick “help” videos to walk clients through the complexity of photoshop, built in.
Ellie | A toolbar UI that can be used with Photoshop (or other tools) with basic commands that can be activated by mouse, keyboard, or voice | A UI that focuses specifically on aspects of the Photoshop UI that the client felt overwhelmed by - e.g. color picker, brush size | A tool integrated into the Wacom tablet that uses gesture commands for tools such as fast copy/paste, line smoothing
Matt | A voice command system that makes it sufficient to complete simple drawing processes for any possible art concepts. | A simplistic UI that will be designed to make navigation easier while using Photoshop | A modification to the Wacom tablet that stores the most common drawing patterns read by the tablet.

## Deliverable C

# Decision Matrix

| Concept | Metric
1 | 2 | 3 | 4 | 5 | 6 | 7 | 8 | 9
Austin | 1 | 3 | 100 | 1.4cm | 5 | 100 | 3 | 0% | No | 5
| 2 | 4 | >10 | N/A | 4 | N/A | 2 | 0% | No | 5
| 3 | 5 | N/A | 50px | 3 | N/A | 4 | 0% | No | N/A
Ben | 1 | 4 | 100 | 50px | 2 | 1 | 4 | 0% | No | N/A
| 2 | 3 | N/A | N/A | 5 | >10 | 3 | 0% | No | 4
| 3 | 5 | 100 | 50px | 4 | 100 | 5 | 0% | No | 5
Callum | 1 | 3 | N/A | N/A | 3 | 100 | 4 | 0% | No | 3
| 2 | 5 | N/A | 50px | 4 | N/A | 4 | 0% | No | 5
| 3 | 2 | N/A | N/A | 1 | N/A | 3 | <10% | No | N/A
Ellie | 1 | 5 | 100 | 50px | 5 | 100 | 5 | 0% | No | 5
| 2 | 5 | 50 | 50px | 4 | 100 | 4 | 0% | No | N/A
| 3 | 4 | 20 | N/A | 2 | 10 | 4 | 0% | No | 5
Matt | 1 | 5 | 20 | N/A | 3 | 20 | 4 | 0% | No | 4
| 2 | 4 | N/A | 50px | 4 | N/A | 4 | 0% | No | 5
| 3 | 5 | 10 | N/A | 5 | 10 | 4 | 0% | No | 5

Each idea was evaluated
against each of the Target Specification metrics.

Ideas that meet the ideal
metric value are shown in
yellow.

## Deliverable C

Simplification of Photoshop UI

- Larger icons, hiding unnecessary tools
- Improvements to the brush selection tool and color picker.
- Voice activation

Integration with Wacom tablet

- Allows the client to maintain their current work environment
- Use as a mouse
- Explore functions with buttons and pen

Command and gesture history and repetition

- Functionality to recreate frequently used processes
- Voice activation

# Selected concept features

## Deliverable C

Help system

- Help build the client’s confidence with Photoshop’s tools alongside the solution

Tactile buttons

- Easier to manipulate than a cursor on the screen
- Large and easy to see

Line smoothing

- Assists client when hands are shaky

# Selected concept features

## Deliverable C

# Functional Decomposition

## Deliverable C

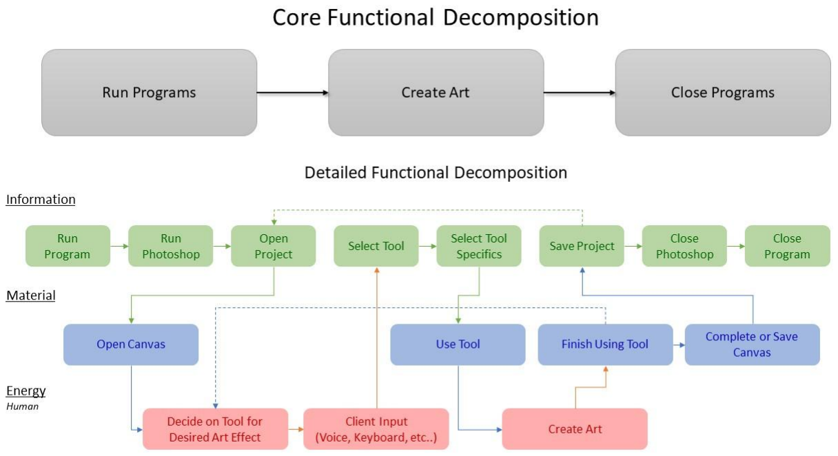
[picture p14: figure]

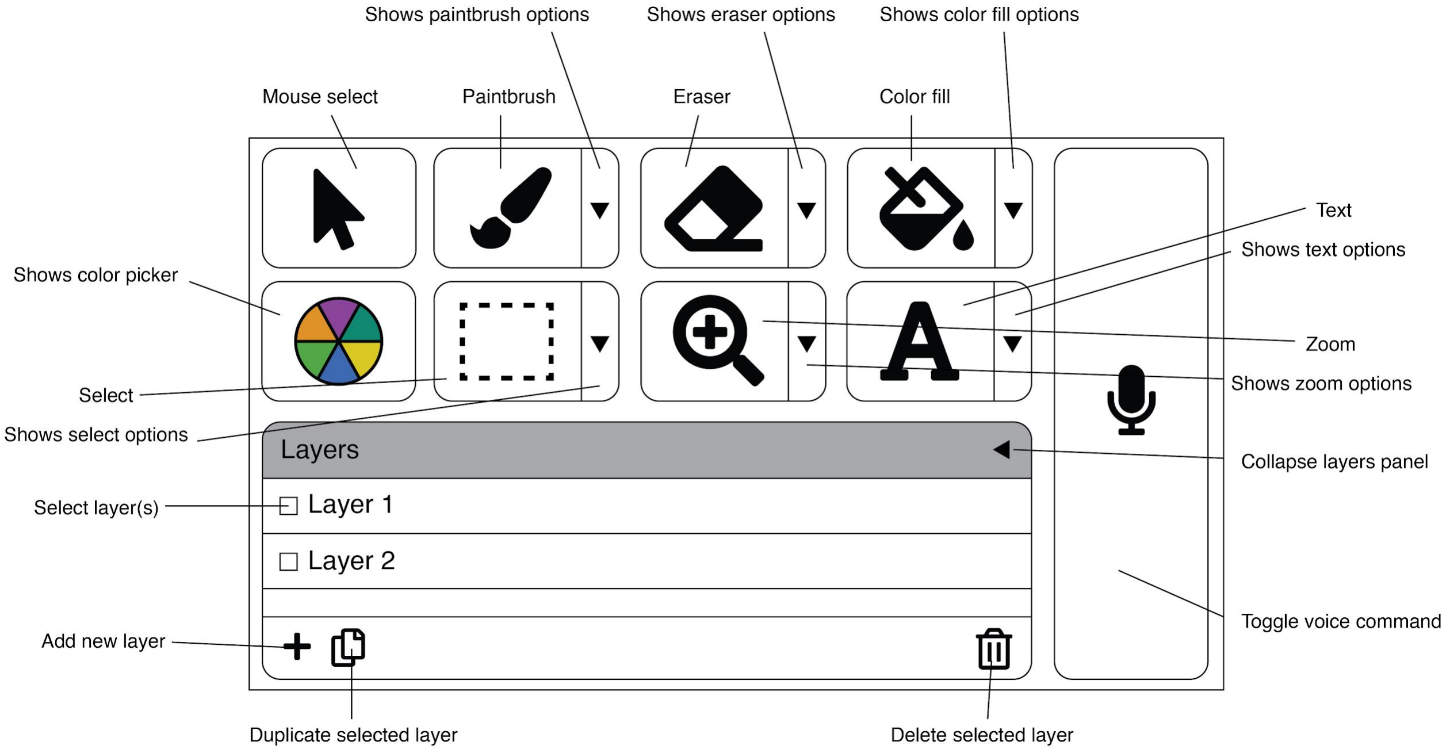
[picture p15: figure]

# Final concept

Solution: auxiliary interface that runs as a desktop application concurrently to Photoshop.
- Controlled by voice, mouse, Wacom tablet (as mouse), or keyboard
- Large icons, simple menu navigation, color picking, and brush selection
- Record of command history that can be repeated.

## Deliverable C

Experience coding desktop applications

- Only Eleanor has any experience building applications from scratch.
- Eleanor uses MacOS, while the client and teammates use Windows.

Voice commands

- Notoriously difficult to implement and unreliable
- Have to use an open-source library

Keyboard mapping

- Keyboard shortcut mapping is limited by the features that have that already built into Photoshop
- Only Austin has direct experience with custom key-mapping and keyboard design from scratch.

# Feasibility: Uncertainties and risks

## Deliverable C

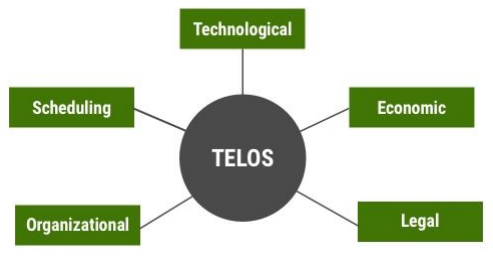
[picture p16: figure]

Technical: Experience and Resources

- Eleanor has experience coding software applications and user interfaces.
- Austin has experience building custom keyboards
- Open-source resources available online (e.g. GitHub repositories)

Economic: Cost Analysis

- All software used in this project is free and open source, decreasing total cost
- A possible economic strategy would be to market towards other disabled artists
- Only cost incurred is the keyboard construction

# Feasibility: TELOS factors

## Deliverable C

# Feasibility: TELOS factors

Legal: Applicable Laws

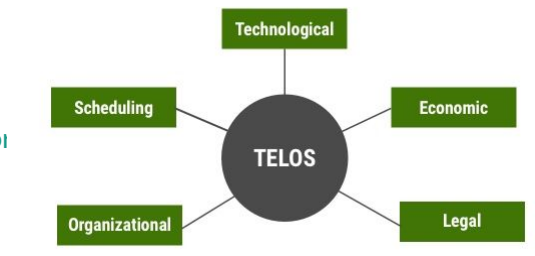
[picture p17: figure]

- Section 17 of the Adobe Legal code prohibits reverse engineering or modifying original source code
- Does not prohibit the use of a new UI on top of Photoshop
- Open-source is free to use on any product created on a personal scale.

Operational: Organizable Constraints and Other Factors

- Other coursework and commitments
- Limited to remote collaboration within group and with client due to COVID-19

Schedule: Deadlines and Reasonability

- Keeping a detailed Gantt chart created in MS project available for group members keeps everyone on track and ensures reasonability.

## Deliverable C

# Low-Fidelity Prototype Overview

Custom Keyboard

- Unsure if the client would be responsive to hardware due to clutter-space
- Need a yes or no on keyboard and keyboard layout design so that we can order parts right away!

User Interface

- Will use keyboard shortcuts to control photoshop underneath
- Simpler, cleaner, but just as powerful
- Contains a new colour picker that avoids the “colour cloud” for colour picking and avoids red

Voice Control

- Uses GAVPI to link voice to keyboard shortcuts.
- A workable prototype has been built already!

## Deliverable D

# Prototype Keyboard Layouts

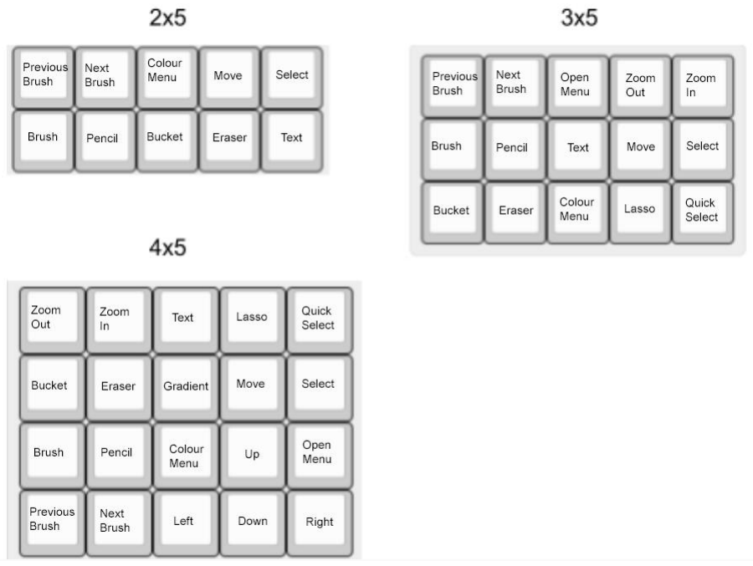
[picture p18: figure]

- 20 common tools were picked based on
Callum’s use of Photoshop
- What needs to be decided early is keyboard size so an accurate bill of materials can be made

## Deliverable D

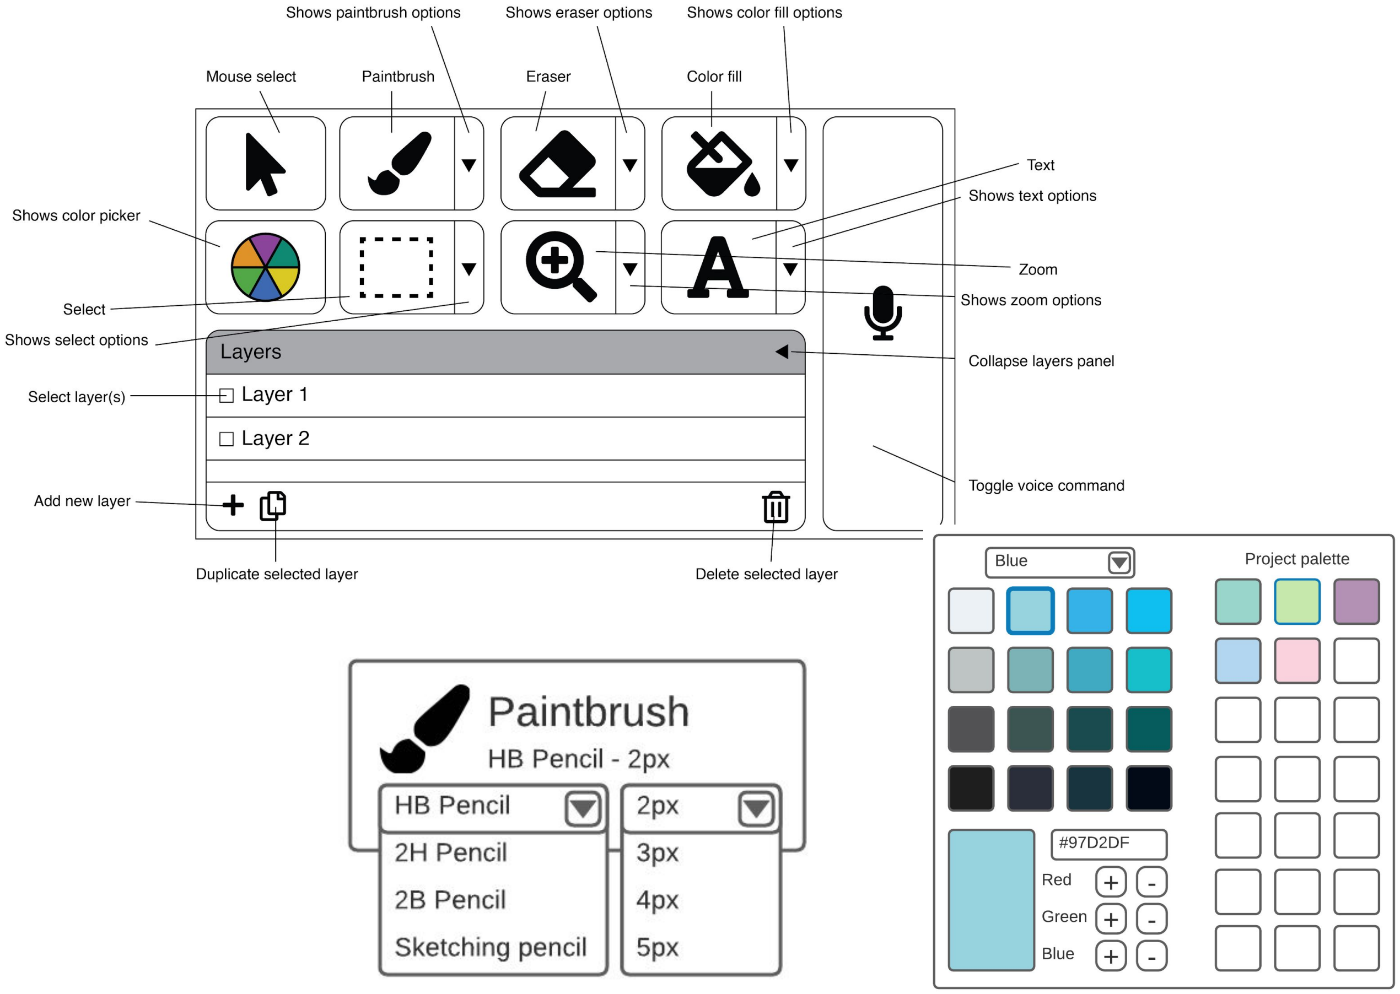
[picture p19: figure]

# Prototype: User Interface

- Avoid a “colour cloud”
- Client has difficulty
differentiating color
- Avoid the colour red
- Make the tool selections larger
- Simplify as much as possible

## Deliverable D

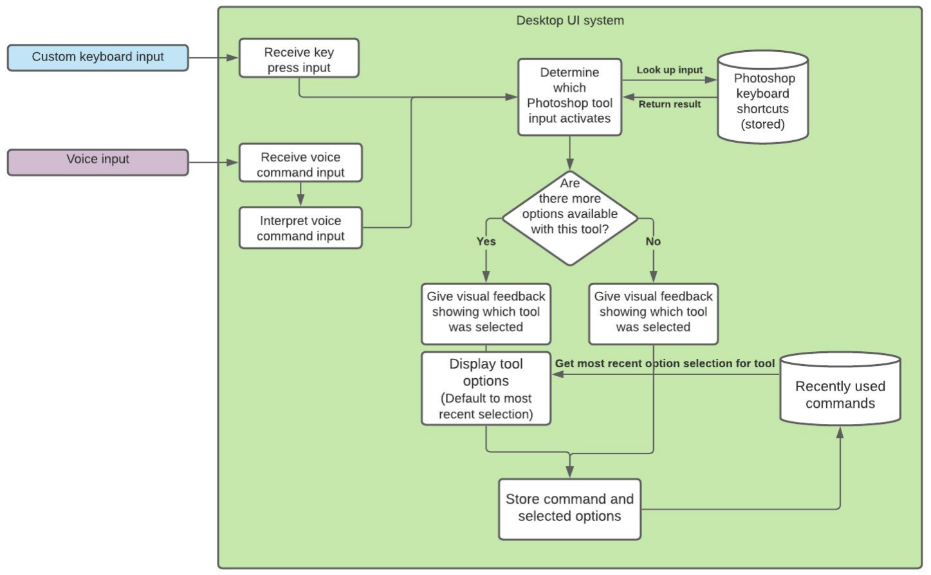
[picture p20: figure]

# Prototype: User Interface

Integration with keyboard and voice input

## Deliverable D

# Prototype: Voice Control

A series of coded keyboard combinations that are linked to voice through an open-source free program called GAVPI.

Examples of common Photoshop pathways

Photoshop Feature | Voice Commands | Keyboard Shortcut Pathway
Open New File | “New File” | CTRL+n
Increase Paint Brush Size | “Brush”, “Increase Size” | b, ]
Duplicate Layer | “Access Layer”, “Go Down”, “Enter” | Alt, right x4, down, down, enter

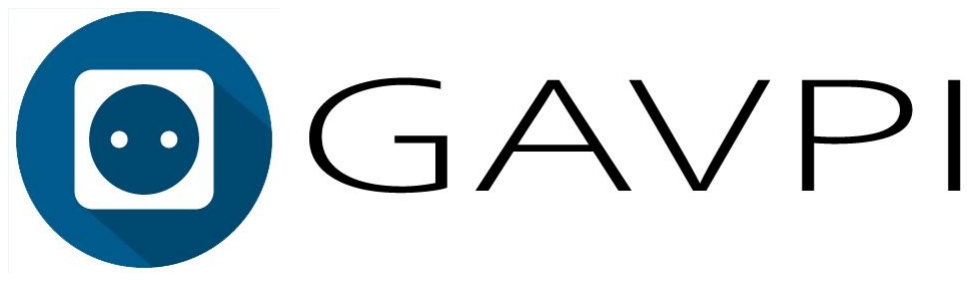
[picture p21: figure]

Write a common word (like “Cat”) | “Text”, “Left Click”, “Type Capital C”, “Type a”, “Type t”, “Enter” | t, left click, Shift down, c, Shift up, a, t, enter
Zoom to full screen canvas | “Toggle toolbars”, “fit to screen” | Alt, CTRL+0

## Deliverable D

# Client feedback (Meeting #2)

# Voice Control and User Interface

- Voice control option that can help call upon shortcuts
- Voice control needs a toggle option to prevent it from always listening
- Simplification of photoshop’s interface with a new UI (toolbar)

Client feedback
- Interested in the voice activation software
- Would like a smoother interface, better colour picker, and a better brush selector

## Client Meeting 2

# Custom keyboard

- Tactile keyboard with shortcuts

Client Feedback
- Make sure keyboard isn’t heavy (>10 lbs)
- Normal keyboard key size is okay
- Larger icons on keyboard, but not so large that they can’t be distinguished from each other

## Client Meeting 2

# Ergonomic pen

- An improved pen for the Wacom tablet to reduce hand discomfort

Client feedback
- Would not necessarily be helpful
- Would not be doing art if hand is in pain

## Client Meeting 2

# Client feedback: Other notes

- Would like a smoother interface, better colour picker, and a better brush selector
- Fast pop-ups are usually not too much of an issue
- The color red is a much worse trigger
- Preferable to have smooth graphics and animations.
- It would be best if the color picker had a border between each color to tell them apart.
- It would be useful to have some feedback when a key is pressed.
- The best colors would be off-white or a soft blue/green.

## Client Meeting 2

# Project plan

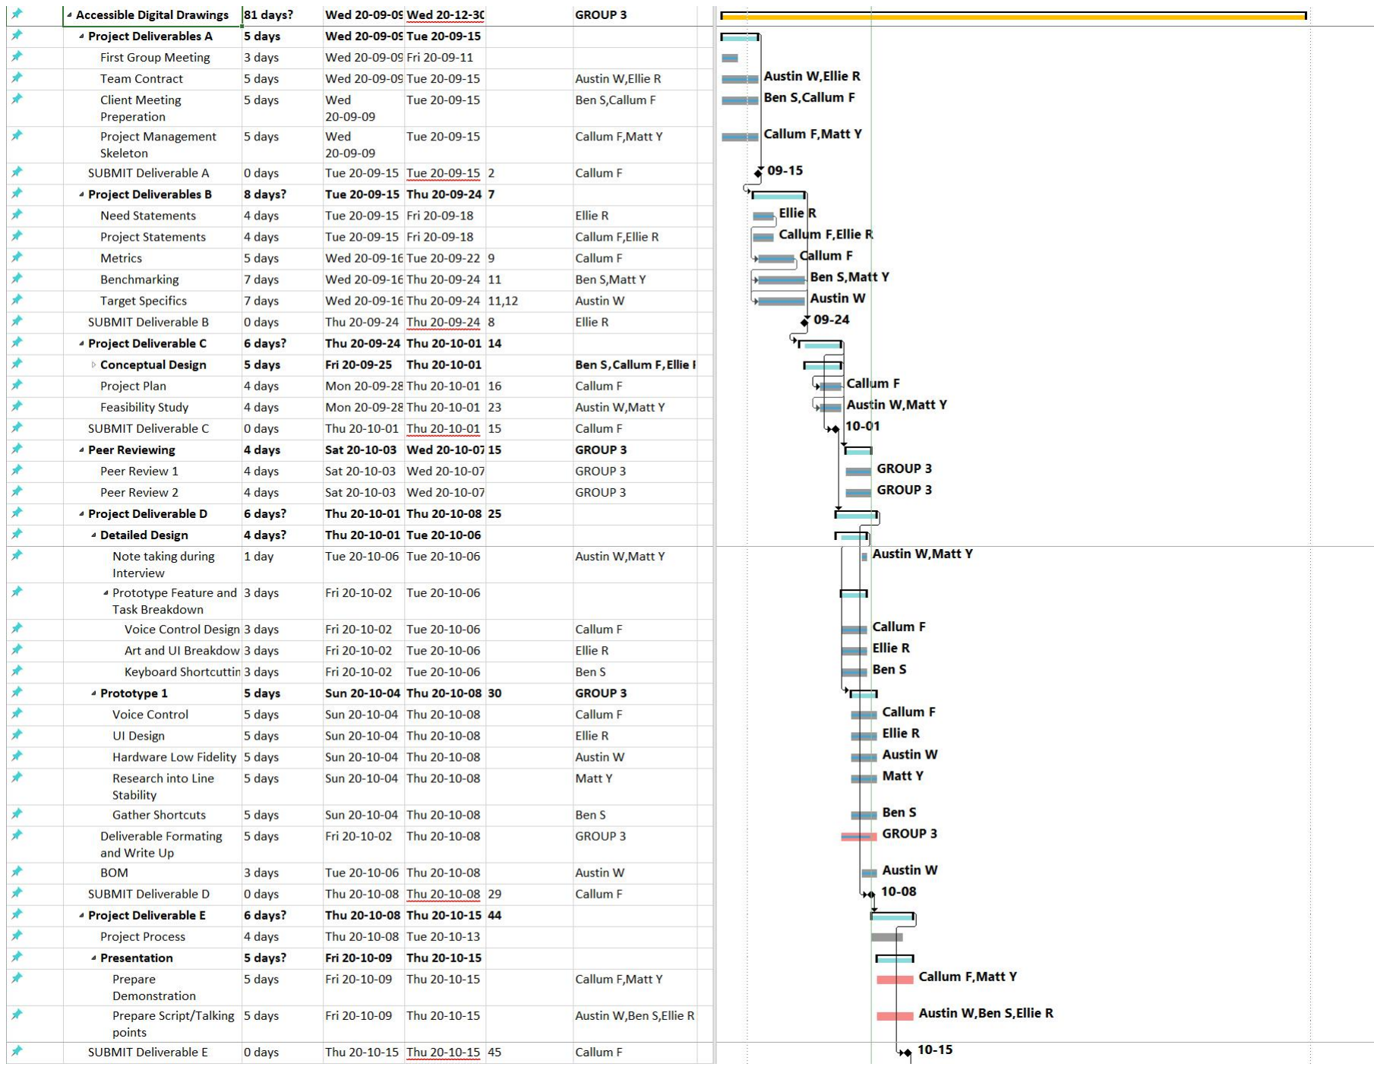
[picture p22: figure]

# Project plan (initial)

- Weekly updates to the MS Project
- Breakdown by deliverables, tasks assigned to team members

## Project plan

# Project plan tracking

- Team has stayed on track!
- After client interview number 2, we have to keep in mind:
- The keyboard construction time and cost
- UI design and software construction time
- Continued consistent communication with the client
- Finalize a team logo and product name

## Project plan

# Plan for future prototypes

# Custom keyboard

- After discussing with the client, they have requested for a 4*5 matrix size
- Keyboard PCB to be designed from scratch, allowing inexpensive, fully custom keyboard
- Custom open source firmware allows for integration with VIA, allowing on demand remapping
- Low cost and affordable, target cost is sub $30
- Design will be open source
- Keyboard components will all be through hole, allowing for DIY

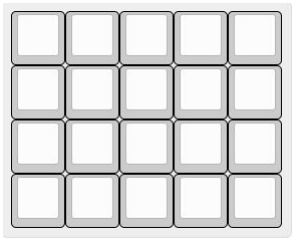
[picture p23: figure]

# User Interface

- Use Electron to build desktop application with JavaScript
- Add notification feedback when input received from voice or keyboard
- Ideally integrate GAVPI code (may research other voice APIs if necessary)
- Add tool options when necessary
- Color picker redesign
- Brush selector
- Ability to toggle voice command

## Future Prototypes

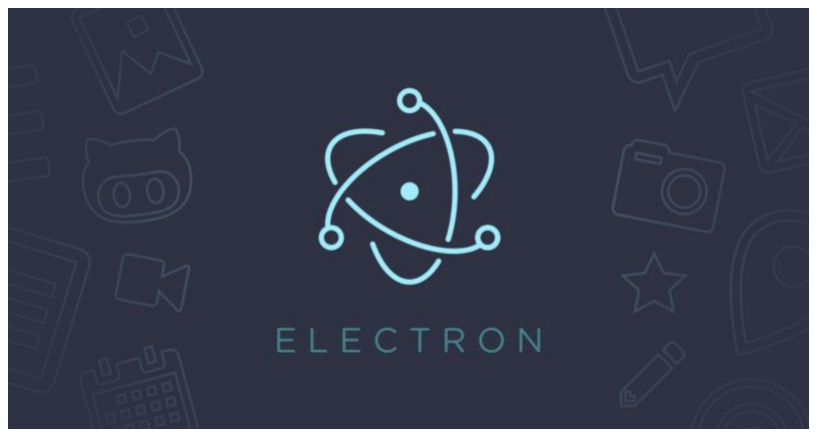
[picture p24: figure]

# Voice command

- GAVPI working prototype
- Can call upon variety of keyboard shortcuts
- Toggle option to begin or stop listening
- Seamless integration with Photoshop and UI
- Minimise amount of setup and configuration needed by user
- Create a detailed instruction manual that contains
- An overview of the technicalities of the voice command system
- A list form of all possible commands
- A detailed instruction manual if the client wants to add their own commands

## Future Prototypes

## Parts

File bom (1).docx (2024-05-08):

###### Table 10: Comprehensive Bill of materials (BOM) for the keyboard prototype

Component | Description | Quantity | Price ($)
ATMEGA32A-PU | Microchip | 1 | 4.67
1-2199299-5 | DIP Socket | 1 | 1.15
512-1N4148TR | Semiconductor | Number of switches | 0.07*20
TZX3V6A-TR | Semiconductor | 2 | 0.27
MF-R050 | Circuit protector | 1 | 0.46
603-CFR-12JR-52-75R | Carbon-Film resistor | 2 | 0.14
MFR-12FTF52-1K5 | Resistor | 2 | 0.19
MFR-12FTF52-10K | Resistor | 1 | 0.19
UMT1H4R7MDD | Capacitor | 1 | 0.28
RDER71H104K0M1H03A | Capacitor | 2 | 0.41
RCE5C2A220J0A2H03B | Capacitor | 2 | 0.64
ABL-16.000MHz-B4Y | Timing crystal | 1 | 0.45
MJTP1230A | Tactile switch | 2 | 0.26
LTL-4222 | LED light | 1 | 0.16
68602-406HLF | Wire housing | 1 | 0.39
USB4085-GF-A | USB receptacle | 1 | 1.3
PCB | Keyboard Shell | 1 | 7
Switches | Switches | Number of switches | 0.2*20
Keycaps | Keycaps | Number of switches | 0.3*20
TOTAL: | | | $ 29.6

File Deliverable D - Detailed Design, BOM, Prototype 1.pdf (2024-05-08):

## Project Deliverable D

-Detailed Design, Prototype 1, and BOM-

Group A3

Austin Wu [300129117]
Benjamin Saulnier [300121338] Callum French [300128814]
Eleanor Rumsey [8274066]
Matthew Yakubu [300123797]

01/10/2020

GNG 2101 – Intro. to Product Dev. and Mgmt. for Engineers

Faculty of Engineering – University of Ottawa

## Table of Contents

Table of Contents | 2
Client feedback summary | 4
Presentation of solutions | 4
Table 1: Solution 1 - UI with voice command | 4
Table 2: Solution 2 - Custom external keyboard for selecting Photoshop tools | 5
Table 3: Solution 3 - Ergonomic pen for Wacom tablet | 5
Discussion questions | 5
Updated and detailed design of concept | 7
Concept breakdown | 7
Voice command system | 7
Keyboard | 8
Interface/Visual feedback | 8
Product assumptions | 9
First prototype | 9
Discussion | 9
Documentation and explanation | 10
Figure 1: High-level mockup of product design, showing inputs and outputs of
system | 10
Figure 2: System flowchart, showing the lower-level interactions between
components | 11
Custom keyboard | 11
Figure 3: Render of sample keyboard | 12
Potential layouts | 12
Figure 4: Examples of possible keyboard layouts | 12
Voice command system | 13
Table 4: Examples of common Photoshop pathways | 13
Desktop UI | 13
Figure 5: Desktop UI flowchart | 14
Figure 6: An example demonstrating relative size and location of the UI overlay14
Color picker | 15
Figure 7: Example colour picker | 15
Brush and tool options | 15
Figure 8: Mockups of visual feedback for tool selection | 15
Testing | 16
Table 5: Target specifications from Deliverable B | 16

Table 6: Partitioned prototypes and their ideal target specifications | 17
Custom keyboard | 17
Table 7: Keyboard prototype and how it will be tested | 17
Voice command system | 18
Table 8: Voice command prototype and how it will be tested | 18
Desktop UI | 19
Table 9: Desktop UI and how it will be tested | 19
Plan for presentation and next client meeting | 19
Bill of Materials (BOM) | 20
Table 10: Comprehensive Bill of materials (BOM) for the keyboard prototype 20
Project Plan Update | 22
Figure 9: Updated project plan for Accessible Digital Drawings group A03 | 22
Appendix | 23
Figure 10: Potential UI design | 23
Figure 11: GAVPI voice command system | 23
Table 11: Glossary of frequently used Photoshop commands and their keyboard
shortcuts | 24

## Client feedback summary

The following table set shows the solutions decided on in Deliverable B that were presented to the client as well as the feedback the client shared after the meeting.

### Presentation of solutions

Three solutions were presented to the client, Madi, in the second client meeting. Solution 1 (UI system with voice command) was the primary solution chosen by the team in Deliverable C. The team also wanted to give Madi a selection of different approaches, so Solution 2 (custom external keyboard) and Solution 3 (ergonomic pen) were also selected as diverse choices in order to prompt additional feedback that might not have been said in the first client meeting. The following tables outline the pros and cons of each solution, as presented to the client, and the feedback received during the meeting. Visual representations of Solution 1 from Deliverable C were also presented to the client, and can be found in Appendix A.

Table 1: Solution 1 - UI with voice command

Pros | Cons | Client feedback
- Minimal cost ● Highly customisable ● Simple to set up and use ● Easily integrated into workflow ● Easy for team collaboration; faster development time ● Easy to use with a tablet, without interrupting motion | ● Will become outdated if Photoshop keyboard shortcuts change ● Not tactile ● Would not be of assistance on a low-vision day ● Voice command systems are new to all team members | ● Interested in the voice activation software ● Would like a smoother interface, better colour picker, and a better brush selector

Table 2: Solution 2 - Custom external keyboard for selecting Photoshop tools

Pros | Cons | Client feedback
- Tactile ● Big buttons are very visible ● Easy to remember where actions are | ● Difficult to collaborate; longer development time ● Not customisable ● Not necessarily with voice (could be discussed) ● Added motions in workflow needed to transition between tablet and keyboard | ● Very interested in tactile keyboard, having own physical toolbar ● Make sure keyboard isn’t heavy (>10 lbs) ● Normal keyboard key size is okay ● Larger icons on keyboard, but not so large that they can’t be distinguished from each other

Table 3: Solution 3 - Ergonomic pen for Wacom tablet

Pros | Cons | Client feedback
- Already a tool used in workflow ● Fixes complaint of tired hands | ● May accidentally press buttons on pen ● Difficult to make ● Difficult to collaborate; longer development time ● No voice command (could be discussed) | ● Little to no interest ● If using the pen was too difficult, they probably wouldn’t try to make art that day

### Discussion questions

After the presentation of the pros and cons of the 3 solutions, the group conducted an open discussion of the solution with Madi. A summary of the team’s questions and client’s answers is as follows:

Should voice command always be on (listening), or be able to be toggled at wish? Having voice command on while the program is in use would be best. If desired, it should be easy to turn it off.

The team was advised against using fast popups or flashing animations for clients with conditions similar to yours. Would you consider a dropdown menu with options to be a fast popup?
Fast pop-ups are usually not too much of an issue; the color red is a much worse trigger. However, it would be preferable to have smooth graphics and animations.

When redesigning the color picker, is there a specific grid size or other features that would help you distinguish between colors?
It would be best if the color picker had a border between each color to tell them apart.

If we were to add some kind of visual feedback such as lights to the keyboard or on-screen notifications, would that be useful for you?
It would be useful to have some feedback when a key is pressed. The best colors would be off-white or a soft blue/green.

In our last meeting, you talked to us about how you use your art for art therapy. Are you hoping to use our solution with your clients, or will it be strictly for you? And if it’s with your clients in mind, do we need to make any considerations for their needs?
The art therapy is usually for people with mental illness rather than physical disabilities. However, the program will be for personal use only.

## Updated and detailed design of concept

The solution feedback and discussion in the client meeting indicated that the client was interested in a solution that integrated a custom keyboard for Photoshop tools. This was different from the solution that the team outlined in Deliverable C, and so some modifications needed to be made.
The updated product concept needs to be a combination of a custom keyboard and voice command system which could both be used to control Photoshop, depending on the user’s preference. There will still be a software component to the product, which provides on-screen feedback and further tool options (such as brush selection and the color picker), but it will no longer be the main focus. Functionality in relation to Photoshop will remain the same; the product will still allow the user to interact with Photoshop tools to create digital art, record recently used commands for reuse, allow the user to smoothen their drawn lines, and provide a new color picker and brush selector.

### Concept breakdown

The product functionality relies heavily on mapping input to keyboard shortcuts to allow the user to manipulate Photoshop tools and navigation. The team has created a glossary of commands (see Appendix B) that the client will be using to create their art; these will be implemented in the system.
The new product concept can be broken down into three main components; the voice command system, the custom keyboard, and an on-screen interface (UI). The functionality and implementation of these components can be further broken down as follows.

Voice command system
The voice command system will be used to provide voice input to the system. This input will be interpreted by the system and mapped to various Photoshop commands. These commands will then be executed in Photoshop using keyboard shortcuts. The priority for voice commands will be tool selection (e.g. “Paintbrush”, “Lasso select”), and menu navigation (e.g. “New file”, “Save file”).
During research in Deliverables B and C, the team discovered the program GAVPI which is free to use and has a public GitHub repository. The team (Callum) has done some preliminary testing with GAVPI and found it easy to integrate with Photoshop keyboard shortcuts. This is a promising solution for the voice command component.
Some further research and experimentation does need to be done for this solution. It remains to be seen whether GAVPI can be easily used along with the other components and other options, such as Google’s Web Speech API will still be considered during the prototyping process. For GAVPI, the team needs to look into its license for reuse, the programming languages it runs on, and whether it has a friendly API for integration with the system.

Keyboard
The keyboard harnesses the same functionality as the voice command system, taking advantage of the pre-existing keyboard shortcuts that exist in Photoshop. Due to the online nature of this year, the keyboard solution wasn’t the first choice for the team as collaboration on a hardware project would be difficult. However, the client absolutely loved the idea of tactile mapping; meaning physically pressing a button to switch between specific tools. In order to meet this specific client need, the keyboard solution has been reintegrated into the project.
To prototype and build this component, it’s important to determine the amount of keys the client would like, which functions these keys should each have, and their respective layouts. Because this is a crucial decision and because the team doesn’t want to shoot low and create a useless piece of hardware or aim too high and create a complicated mess of keys, feedback from the client is important before continuing much further.
Once the final layout is decided and parts are ordered, a keyboard specialist on our team (Austin) will wire up the board, load on the firmware, and ensure that everything is working properly.

Interface/Visual feedback
The use of keyboard shortcuts only solves one of the accessibility issues that the client faces. Even with added buttons and voice capability, Photoshop is still cluttered and confusing. Creating a cleaner visual interface that shows when tools are in use, when the voice command system is listening, and simplifies the brush selection menu and color picker will help to make Photoshop more usable for the client.
The client also expressed an explicit need to avoid the colour red. This is to avoid triggering seizures. While avoiding red when building the softwares interface is simple, it also raises an interesting problem. Photoshop, and almost any other digital art programs, starts all of their colour selectors at a harsh red. Both because of this and the clients difficulty separating colours when they are presented in a colour cloud, the newly designed UI will have to feature a completely redesigned colour picking system.
Integrating this into Photoshop will require some experimentation, but since much of Photoshop is accessible through keyboard shortcuts and the rest of the parts of this prototype focus around them, there is no reason the user interface (UI) can’t take advantage of this as well. Newer editions of Photoshop allow users to set their own shortcuts. Combining this feature with the fact that any colour can be represented in code through a hex code, RGB values, or HSV values, fully integrating the new UI so that it makes Photoshop a friendlier experience shouldn’t be too difficult.

The final product of all of these parts is a fully integrated single software overlay with an external keyboard that contains all the functionality listed above and opens with Photoshop when the client accesses the app. This software should take no extra effort to use but provide the client with all of the accessibility they desire.

## Product assumptions

Product assumptions lay out the bias or opinions on the product they are creating. In this case, many of the product assumptions are related to the clients disability. This product hopes to decrease the hurdle of the disability by providing many alternative solutions to the same problem. For example, if the client can’t talk well on a particular day, the keyboard and UI will both contain keyboard shortcuts that can access tools without using the voice commands. The client did express though that on a particularly bad day where they couldn’t move their hand or couldn’t see, they would not be making any art, digital or otherwise. With all of that said, the following is a list of product assumptions:

- The product acts as an overlay for Photoshop
- The overlay can communicate with Photoshop through keyboard shortcuts
- The overlay can be used to enable and disable voice controls
- The user has enough hand mobility to be able to press some keys
- The user is able to talk loud enough for voice control
- The user has a microphone to allow audio input into their computer
- The user uses a windows computer to create their art
- The user knows the names of the tools that they want to use, and is able to call upon them
- The product allows the user to create digital art under many circumstances that prevented them from completing projects before

## First prototype

### Discussion

Much of the explanation of the product can be found above in the detailed design breakdown. In summary, the final product will be a three-part solution containing an external keyboard, voice-command capabilities, and a simplified UI that all work together to make Photoshop a more accessible and enjoyable experience.
The prototypes in this deliverable are low-fidelity. For this project, that means that three parts have been divided and worked on separately. The keyboard has had a quick visualization of possible shapes and numbers of functions available that will be sent off for the client to pick from. The software and overlay prototype is focused on a higher level visualisation of the entire system, as it acts as the central “hub” that intercepts information from the input sources.The voice control has been a focused prototype and has almost been completely built. It is now being tested through dogfooding, where the creation team uses their own product in house (i.e. this team using it to create diagrams). As the final prototype approaches, these three parts will be joined together to create one final product. Since this is the first prototype as well, everything has been kept low cost. No budget has been spent creating designs, programming the voice control, or in building keyboard designs.

### Documentation and explanation

The following two diagrams show a broad overview of the final project. Two input sources, from a microphone or a keyboard, will be linked to a software overlay that will interpret the input and use it to manipulate photoshop. This overlay also acts as an output, showing which tools are selected much clearer than in photoshop.

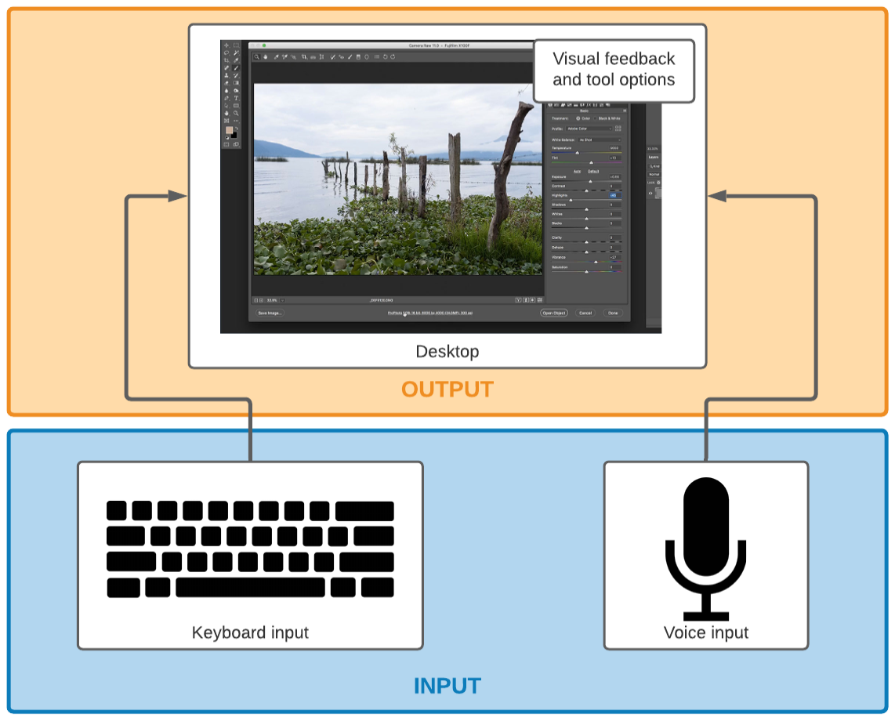
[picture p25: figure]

Figure 1: High-level mockup of product design, showing inputs and outputs of system

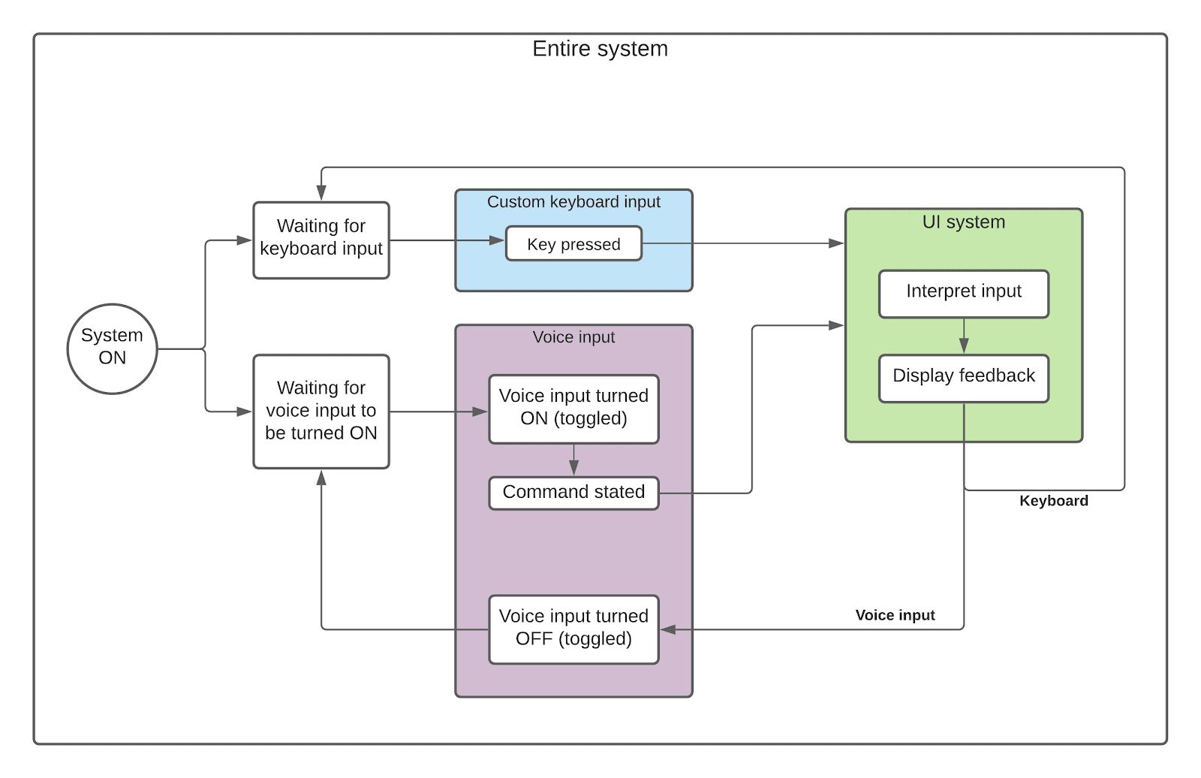
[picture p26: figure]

Figure 2: System flowchart, showing the lower-level interactions between components

Custom keyboard
This is an initial render for the custom keyboard. The team will be closely collaborating with the client in order to determine the optimal key layout for their needs. The final keyboard design and render may differ from the current render. It will be designed with Fusion 360 and rendered with an on board rendering engine.

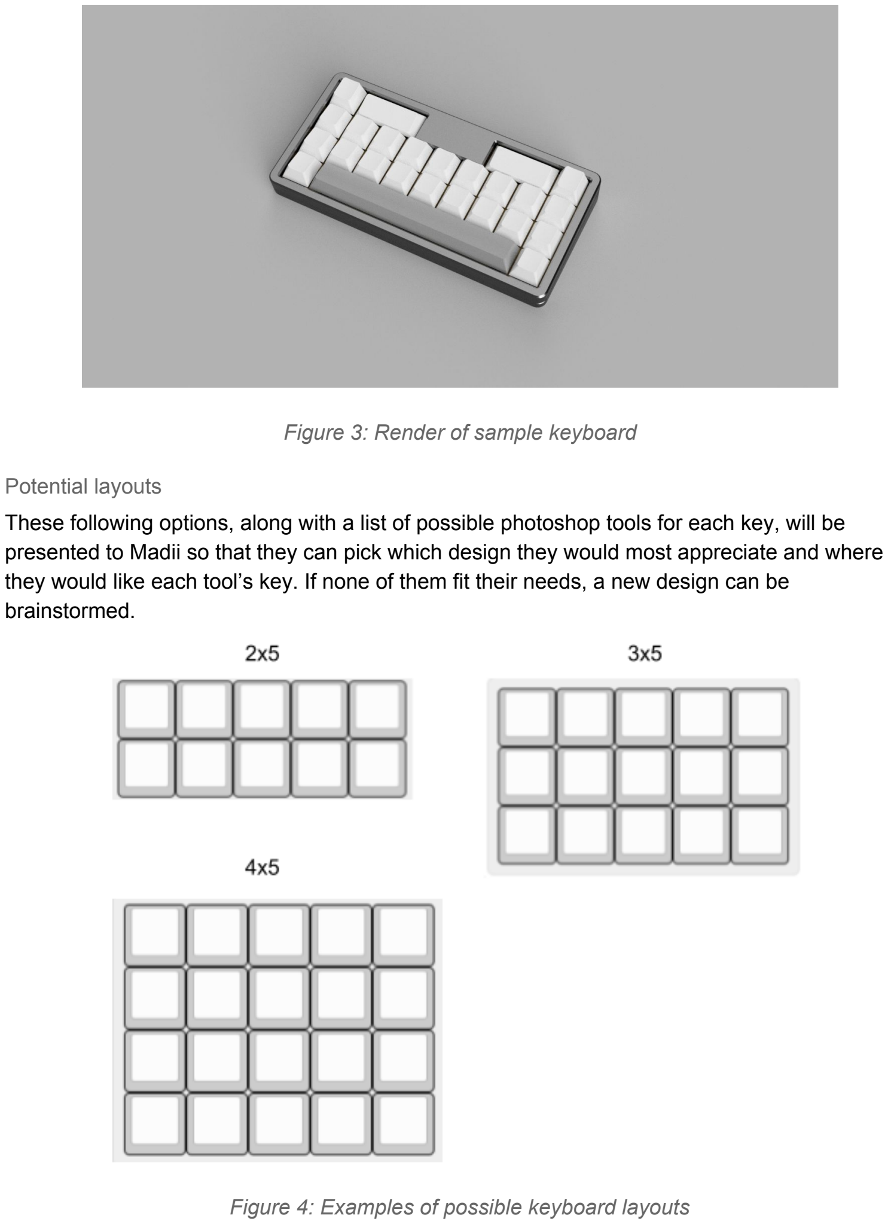
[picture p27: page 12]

Figure 3: Render of sample keyboard

Potential layouts
These following options, along with a list of possible photoshop tools for each key, will be presented to Madii so that they can pick which design they would most appreciate and where they would like each tool’s key. If none of them fit their needs, a new design can be brainstormed.

Figure 4: Examples of possible keyboard layouts

Voice command system
This voice command system uses the GAVPI software to map voice commands to keyboard commands and even entire keyboard shortcuts. Currently there are 140 different possible voice commands recorded in the software, though this number might increase. Of these 140 different voice commands though, only 16 use “unique” voice paths. Part of these voice paths is a confirmation from the computer that the action has been completed. This is done through an automated voice and audio feedback.
For some examples of pathways, see Table 4 below. Included is the desired effect in Photoshop, the voice commands one would have to say for that effect, and then embedded keyboard shortcuts that GAVPI runs through. In the final product, a user manual will be provided with an all encompassing library of possible commands.

Table 4: Examples of common Photoshop pathways

Photoshop Feature | Voice Commands | Keyboard Shortcut Pathway
Open New File | “New File” | CTRL+n
Increase Paint Brush Size | “Brush”, “Increase Size” | b, ]
Duplicate Layer | “Access Layer”, “Go Down”, “Enter” | Alt, right x4, down, down, enter
Write a common word (like “Cat”) | “Text”, “Left Click”, “Type Capital C”, “Type a”, “Type t”, “Enter” | t, left click, Shift down, c, Shift up, a, t, enter
Zoom to full screen canvas | “Toggle toolbars”, “fit to screen” | Alt, CTRL+0

Desktop UI
The desktop user interface (UI) intercepts keyboard and voice input and outputs relevant information to the user. A flowchart describing its functionality is shown below (Figure 5). Low-fidelity prototypes of the components have been created for the UI output, and their exact aesthetics and layout will be refined in future client meetings and prototype iterations.

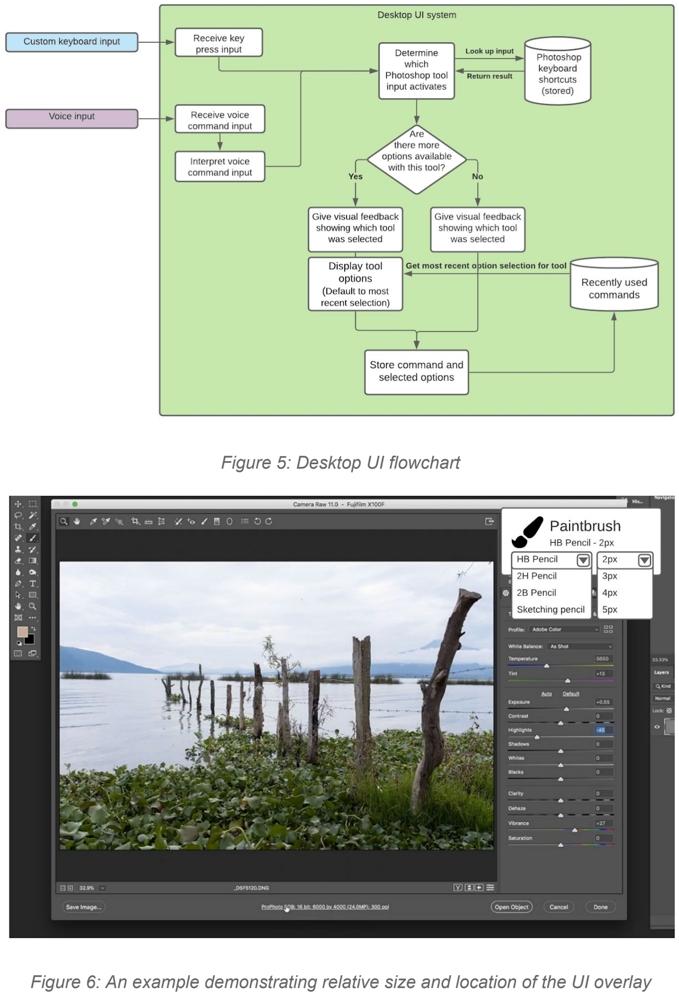
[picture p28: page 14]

Figure 5: Desktop UI flowchart

Figure 6: An example demonstrating relative size and location of the UI overlay

Color picker
A newly designed colour picker is shown below. It features an option to pick from predetermined colour palettes, a project palette that shows common colours that have been used in the project so far, separations between neighbouring colours, and an RGB colour selector. Instead of sliders, these values can be adjusted using button inputs to avoid accidentally creating a sudden red. The entire design is focused around avoiding red and avoiding having the colours arranged in a “cloud” so that Madii knows precisely which colour they are using.

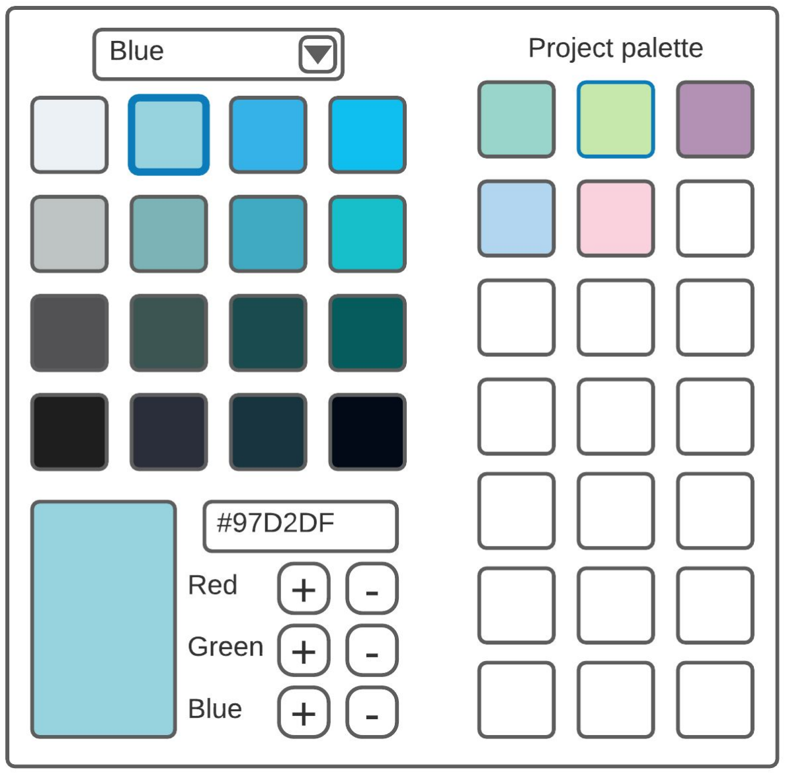
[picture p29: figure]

Figure 7: Example colour picker

Brush and tool options
Following are two examples of visual feedback for further tool option selection. These would change as different paint brushes or fonts are selected.

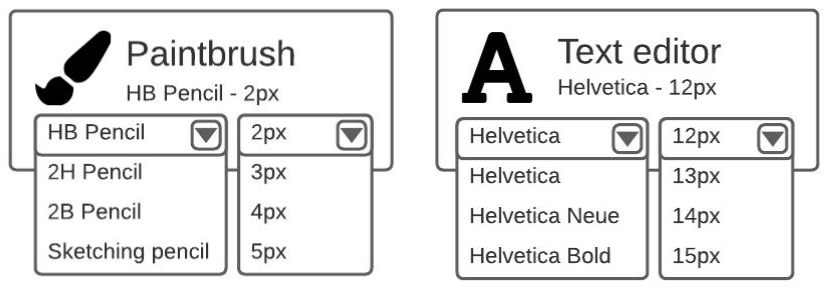
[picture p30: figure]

Figure 8: Mockups of visual feedback for tool selection

### Testing

In the testing section of this document, how each of the parts of the overall prototype work to meet the design criteria established in Deliverable B as well as their respective testing methods are explored. Because product assumptions were decided based on the design criteria and the client interviews, it seems fair to compare them to the metrics established in previous deliverables. Immediately below is a table with the target specifications and ideal values from Deliverable B.

Table 5: Target specifications from Deliverable B

| Metric | Units | Ideal | Acceptable
1 | UX as empathetic with client | Personal ranking | 5 | 4-5
2 | Number of repeatable functions | Positive integer (count) | 100 | 20-100
3 | Icon size | px or cm (on-screen) | 50px/2.5cm | 35-100px/ 1.4-3.0cm
4 | Customizability | Personal ranking | 5 | 3-5
5 | Number of commands recorded | Positive integer (count) | 100 | 50-100
6 | Assistive features | Personal ranking | 5 | 5
7 | Prevalence of red | % on startup | 0% | <10%
8 | Presence of fast pop-ups | Yes/No | No | No
9 | Hardware Integrability | Personal Ranking | 5 | 5

Using the above target specifications, the ideal values for each of the prototype parts have been listed in a table below. Because this project has broken into three parts, it is important to see how each individual part helps to reach the final project target specifications. Table 6 shows a breakdown of how each individual part will be tested for each metric.

Table 6: Partitioned prototypes and their ideal target specifications

Metric | Custom keyboard | Voice command system | Desktop UI
1 | 5 | 5 | 5
2 | 100 | 100 | Maximum of value for keyboard and voice command
3 | 1.4cm | 50px | 5cm x 3cm
4 | 5 | 5 | 4
5 | 0 | 0 | 10
6 | 4 | 5 | 3
7 | 0% | 0% | <10%
8 | No | No | No
9 | 5 | 4 | 5

Custom keyboard
Since this is a low-fidelity prototype and the keyboard components can only be purchased once, it is important to decide on a final design before beginning construction. Because of this, testing focuses on client empathy, ensuring that they feel comfortable with the keyboard and options they would receive.

Table 7: Keyboard prototype and how it will be tested

Metric | Testing performed
1 | UX as empathetic with client | Offering between three choices. At the time of writing, the client has not decided on which they would prefer, but the test will conclude once they decide on a shape.
2 | Number of repeatable functions | Either 10, 15, or 20 based on client choice
3 | Icon size | Standard keyboard size (14mm), extra spacing between

4 | Customizability | Based on client choice.
5 | Number of commands recorded | N/A
6 | Assistive features
7 | Prevalence of red | Keyboard will remain monochromatic (black or white)
8 | Presence of fast pop-ups | No
9 | Hardware Integrability | Simple connection to the PC through USB.

Voice command system
The voice command system works by using keyboard shortcuts already built into photoshop. Because each voice-command is mapped to a keyboard pathway, they can be tested using an online “keyboard press detector” to ensure the input is going through the right keys. Additionally, the system can be continually tested throughout the project as photoshop is used to create artwork and displays for other deliverables.

Table 8: Voice command prototype and how it will be tested

Metric | Testing performed
1 | UX as empathetic with client | The UX to program is not the friendliest, but it is simple once the initial programming is done. Will be tested with the Client. Dogfooded as well
2 | Number of repeatable functions | Testing will be done to see if the number is too overwhelming.
3 | Icon size | N/A
4 | Customizability | Agile style testing to ensure the client is happy with the final result
5 | Number of commands recorded | Testing will be done with the client and through dogfooding.
6 | Assistive features | Continued testing to see if the voice input is at an acceptable quality for aid.
7 | Prevalence of red | N/A
8 | Presence of fast pop-ups | N/A

9 | Hardware Integrability | Test with clients specific microphone and shortcuts

Desktop UI
The desktop UI is tested using an agile design system, where constant feedback between the client and the development team ensures that the final product is functional and polished.

Table 9: Desktop UI and how it will be tested

Metric | Testing performed
1 | UX as empathetic with client | Looking at the size, shape, and feel of the UI component mockups that have been created
2 | Number of repeatable functions | N/A
3 | Icon size | Measured based on UI mockups
4 | Customizability | Measured based on UI mockups
5 | Number of commands recorded | Estimated for the moment; will start at 10 but depends on the method of storage chosen in upcoming prototypes (e.g. Array, text file, json, database)
6 | Assistive features | For the UI alone, there are very few accessible features other than large icons and font size. This is not the accessibility-focused component of the overall design.
7 | Prevalence of red | Due to the color picker, it is impossible to completely eliminate red from the design.
8 | Presence of fast pop-ups | The animation speed for dropdown menus will be controlled to a slow animated slide.
9 | Hardware Integrability | The primary goal of the UI system is to integrate the keyboard and voice input systems and can be controlled using the Wacom tablet as a mouse.

### Plan for presentation and next client meeting

In the presentation, the group hopes to show off a combination of each of the parts of the prototype. Since the keyboard and UI remain very conceptual prototypes, they can be demonstrated in the presentation and client meeting through diagrams. However, since the presentation is ten minutes long, if there is time the voice control functionality can be demonstrated to show just how effective the prototype is.

### Bill of Materials (BOM)

Since this project does include hardware, a keyboard, it will need a complete Bill of Materials (BOM). However, since the final price is still undetermined (due to the need for client input on design), the BOM remains a rough estimate. Since the keyboard options presented show a minimum of 10 keys and a maximum of 20, these values are used to give a rough quoted price range. This quoted price range does not include the price of parts that cannot yet be determined or the price of shipping, but seeing the current number, keeping the project within budget seems more than possible. Most of the materials for the BOM are for a custom circuit board, the electronic components and other various components required to make the keyboard.

Table 10: Comprehensive Bill of materials (BOM) for the keyboard prototype

Component | Description | Quantity | Price ($)
ATMEGA32A-PU | Microchip | 1 | 4.67
1-2199299-5 | DIP Socket | 1 | 1.15
512-1N4148TR | Semiconductor | Number of switches | 0.07*Quantity
TZX3V6A-TR | Semiconductor | 2 | 0.27
MF-R050 | Circuit protector | 1 | 0.46
603-CFR-12JR-52-75 R | Carbon-Film resistor | 2 | 0.14
MFR-12FTF52-1K5 | Resistor | 2 | 0.19
MFR-12FTF52-10K | Resistor | 1 | 0.19
UMT1H4R7MDD | Capacitor | 1 | 0.28
RDER71H104K0M1H 03A | Capacitor | 2 | 0.41
RCE5C2A220J0A2H0 3B | Capacitor | 2 | 0.64

ABL-16.000MHz-B4Y | Timing crystal | 1 | 0.45
MJTP1230A | Tactile switch | 2 | 0.26
LTL-4222 | LED light | 1 | 0.16
68602-406HLF | Wire housing | 1 | 0.39
USB4085-GF-A | USB receptacle | 1 | 1.3
PCB | Keyboard Shell | 1 | Undetermined as of right now
Standoffs & Screws | Screws | 1 set | 5
Switches | Switches | Number of switches | 0.4-0.7 * Quantity
Keycaps | Keycaps | Number of switches | Undetermined as of right now
TOTAL: | | | ~$22.57-$27.27

## Project Plan Update

A copy of the updated project plan can be seen below. Due to sickness, Austin was less available for this deliverable, and due to midterms and other requirements, both Callum and Ellie will be less available for Deliverable E. With this in mind, tasks have been grouped up, and we have all pitched in to give extra help to complete these deliverables. Attached with this deliverable is a PDF copy of the project plan in higher resolution.

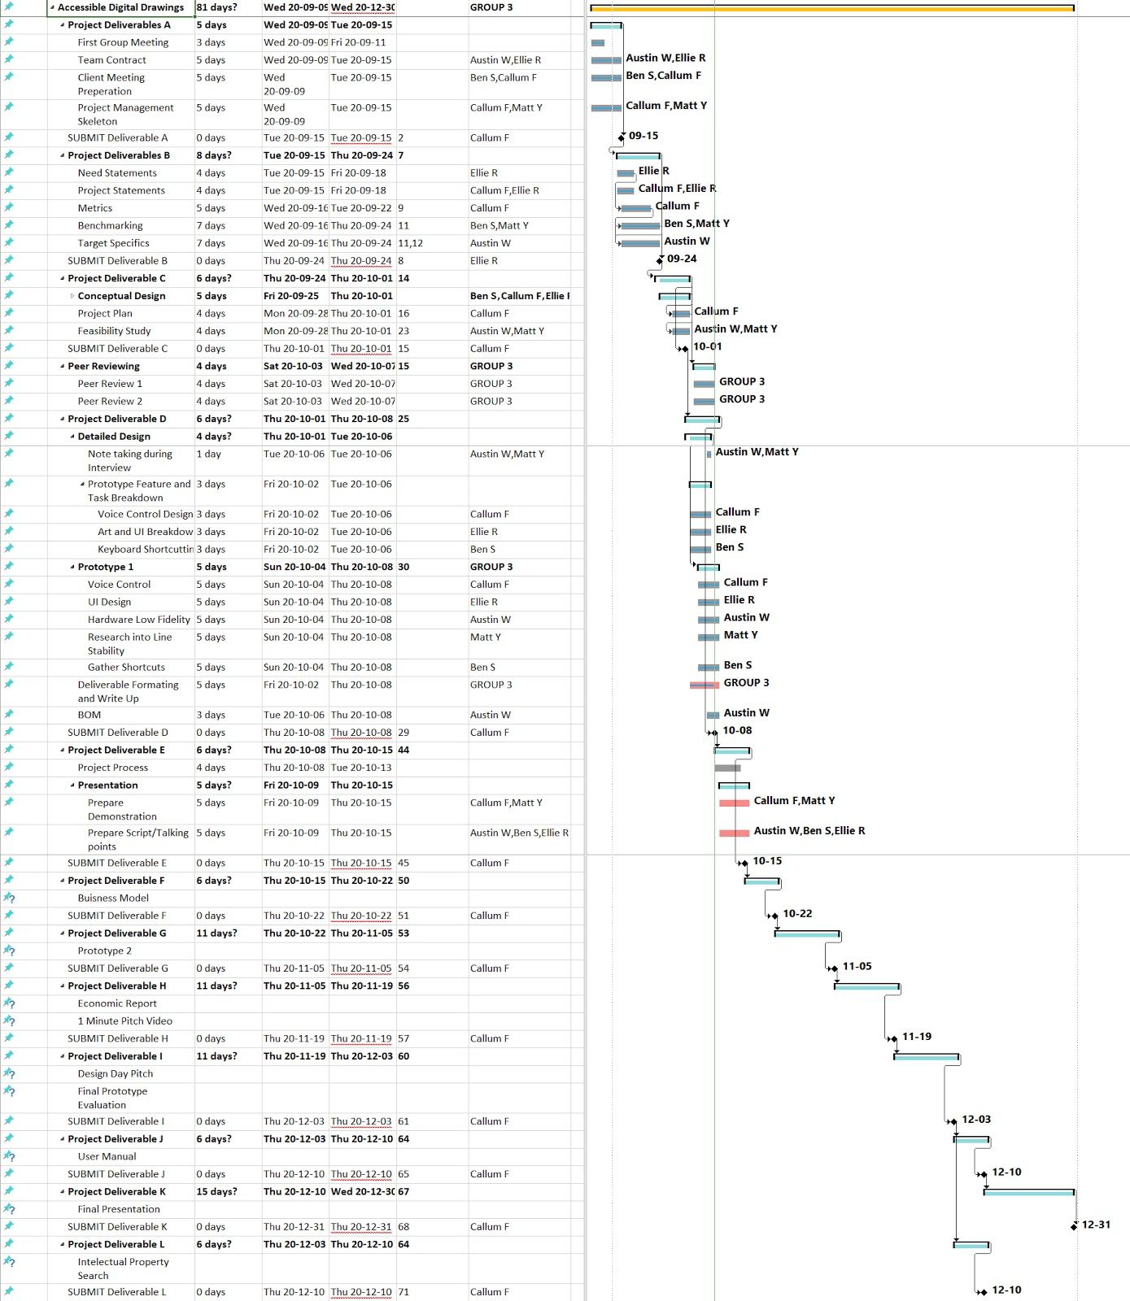
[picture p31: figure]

Figure 9: Updated project plan for Accessible Digital Drawings group A03
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

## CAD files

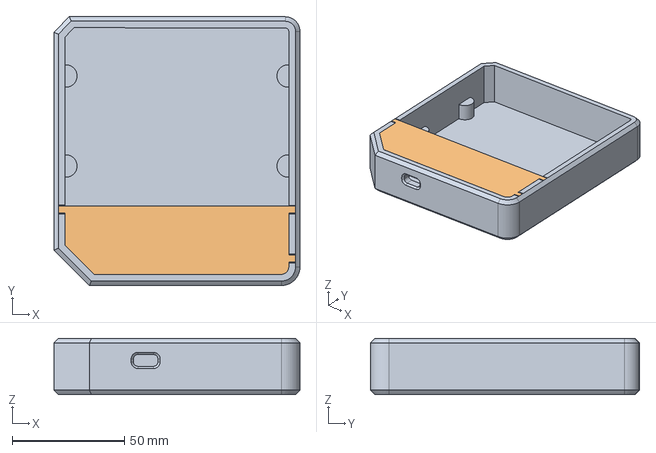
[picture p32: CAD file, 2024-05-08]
Case.step
109.7 x 120.0 x 25.0 mm

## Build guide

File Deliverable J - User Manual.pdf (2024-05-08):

## Project Deliverable J

User Manual

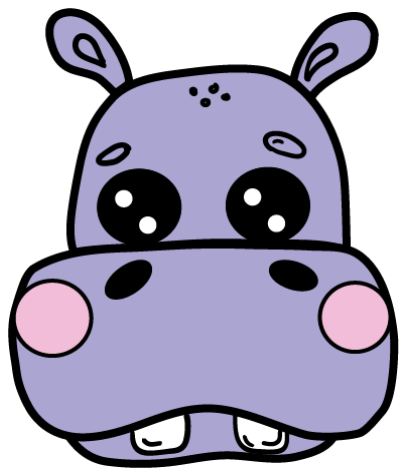
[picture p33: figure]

Group A3

Austin Wu [300129117]
Benjamin (Ben) Saulnier [300121338] Callum French [300128814]
Eleanor (Ellie) Rumsey [8274066] Matthew (Matt) Yakubu [300123797]

07/12/2020

GNG 2101 – Intro. to Product Dev. and Mgmt. for Engineers

Faculty of Engineering – University of Ottawa

# Abstract

Digital photo making and art apps are notoriously complex. The thing is, they need to be and that complexity is not a bad thing. It allows for the creation of digital masterpieces and the embracing of a multitude of artistic styles into a single medium. That said, the complexity of a software does not make it very inviting for artists with a barrier. This barrier could be anything, from a disability to inexperience. This is where we step in to help with our product: Helpo.

Helpo is a photoshop assistant. It’s job is to simplify photoshop and make it more accessible so that any artist with a barrier can still recreate the masterpiece in their mind in the digital landscape. Hello does this by being able to take in input in various forms, like button presses on a physical keyboard or with voice commands. It then uses this input to control photoshop through the keyboard shortcuts that are already built into the program. So a task that would have initially taken the opening of a menu, scrolling through it, and confirming the selection can now be done simply by saying a word.

This product was built and designed with accessibility in mind. The client Helpo was built for is a student who hopes to use art as a means of therapy. Being able to create is integral to their mental health, and it is a practice that they hope to share with others. Only one problem: they have a fluctuating disability. This means that one day, our client could be functioning just as well as anybody else and then seem almost catatonic on the next. To understand where our client was coming from, many interviews were conducted which ultimately resulted in certain design specifications that would be necessary to promote accessibility. These included a minimization of the colour red in the application (which could trigger seizures), including large buttons, the possibility to integrate the software into equipment they already owned, and the option for multiple forms of input and feedback. Keeping these specifications in mind, Helpo was born.

The Helpo product can be separated into two distinct sections: the software and the hardware. The Helpo software is built on top of a voice-to-keyboard input framework called GAVPI. It has been altered to include large buttons and so that a profile for the voice commands is already integrated. This software gives the user both auditory feedback on the switching of a tool and visual feedback in the form of a light up button for Photoshop twenty most common tools. Helpo’s hardware component is a simple 4x5 keyboard with those same twenty most common tools. It can be plugged into any computer and be used in conjunction with a regular keyboard to make making art and switching tools even more seamless.

This document is a comprehensive user manual for all aspects of Helpo. It contains install instructions, troubleshooting, instructions on how to use the application, and optional further customization, as well as containing a technical summary of both the software and hardware guidelines. It also contains the health and safety guidelines to follow and concludes with an appendix detailing the final price and a list of every possible command that Helpo can perform.

Helpo is built for the user first. We hope that this product and manual can guide you on the journey to creating your own digital masterpieces no matter the personal barriers you may have.

# Table of Contents, List of Figures, List of Tables

Abstract | 2
Table of Contents, List of Figures, List of Tables | 3
Introduction | 4
Instructions for installation | 5
Installing Helpo | 5
Troubleshooting installation | 8
Using Helpo | 10
Introduction | 10
Using Helpo with Photoshop | 11
Making your own keyboard shortcuts | 11
Master list of possible commands | 12
Optional customisation | 13
Building your own profile | 13
Installing VIA for Custom Keyboard Mapping | 18
How to use VIA | 19
Technical summary | 21
Software prototyping summary | 21
Software troubleshooting | 21
Hardware prototyping summary | 21
Health and Safety Guidelines | 23
Hardware Troubleshooting | 23
Hardware Alteration | 24
Conclusions and Recommendations for Future Work | 25
Appendices | 26
A1. The Helpo keyboard Bill of Materials (BOM) | 26
A2. Comprehensive list of voice commands in the Helpo profile | 27

# Introduction

Understanding the fundamentals of Photoshop without prior technical experience can prove to be quite difficult, especially for any artists looking to transition into the digital medium. Helpo is here to make that transition a little easier, for every kind of artist looking to expand upon their creative side. The main focus of Helpo is to make it easier to maneuver around Photoshop in more ways than one. For users that may have a hard time using any form of hardware to control their device, Helpo has a voice command system that has been implemented to allow for users to navigate through the application hands-free. However, Helpo is not limited to just Photoshop.

Helpo was initially developed for a target audience, but has expanded since then. Originally, Helpo was intended to modify Photoshop into a more accessible platform for disabled young artists to create freely. Our client found that their struggles with Photoshop created more stress whenever they tried to use it, which limited their ability to execute their ideas online. During the various client meetings throughout the semester, we discovered that the UI was a point of focus, so we made it our goal to address that in our final product to improve our clients user experience. Photoshop has a cluttered and unfriendly interface that was especially challenging for our client, so our ideal solution would allow them to continue using Photoshop or other various digital drawing tools with a product that would provide additional and affordable functionality that could simplify the interface. This solution would allow multiple options for input, including voice and/or keyboard input.

As previously mentioned, Helpo was developed to make Photoshop a more inclusive experience for any sort of artist. When the team was assigned this project, the only requirement was to develop a software solution that could meet all of our client’s needs. Helpo took that one step further and added a hardware component at our clients request. Helpo works through the use of keyboard shortcuts, which were chosen specifically by our client with a corresponding keyboard that include the same shortcuts to accommodate for our on the days that they are unable to use the voice command system. The key caps were also designed with symbols that associated well enough with their respective tools to be considered self-explanatory at first glance. We also observed that some of our competitor’s had diverted to other digital art software or created entirely new ones as an alternative to the solution our client specifically asked for at the beginning of the semester. Overall, we believe that Helpo is more versatile than other solutions may appear to be as it accommodates for all aspects of our client’s fluctuating disability.

# Instructions for installation

## Installing Helpo

The following is a step by step instruction guide on how to get and launch Helpo to help you with your photoshop experience. Please note, Hello currently only works on a Windows operating system. If you have a Mac, this download will not work.
1. Visit the following link
(https://makerepo.com/Frenchfrie/helpo-your-photoshop-assistant). Once here find the section labelled “project files” on the right side of your screen. Download the files labeled “Helpo_8.zip” and “Helpo.XML”. We recommend saving these into a folder that you can easily find.
2. Go to your folder in which the “Helpo_8.zip'' file is located. Left click on the “Helpo_8.zip” file to select, then right click to open the menu. Once opened, select “Extract all”. This will open a window asking you for a save destination. If you are at your desired file location, select “Extract”.
3. A new folder should have appeared with the name “Helpo_8”. It will look similar to the .zip file, but no longer have the zipper sealing it shut. Double click on this folder. A second folder, also labelled “Helpo_8” should appear. Double click on this folder as well. It will open up and have three files in it, as shown below.

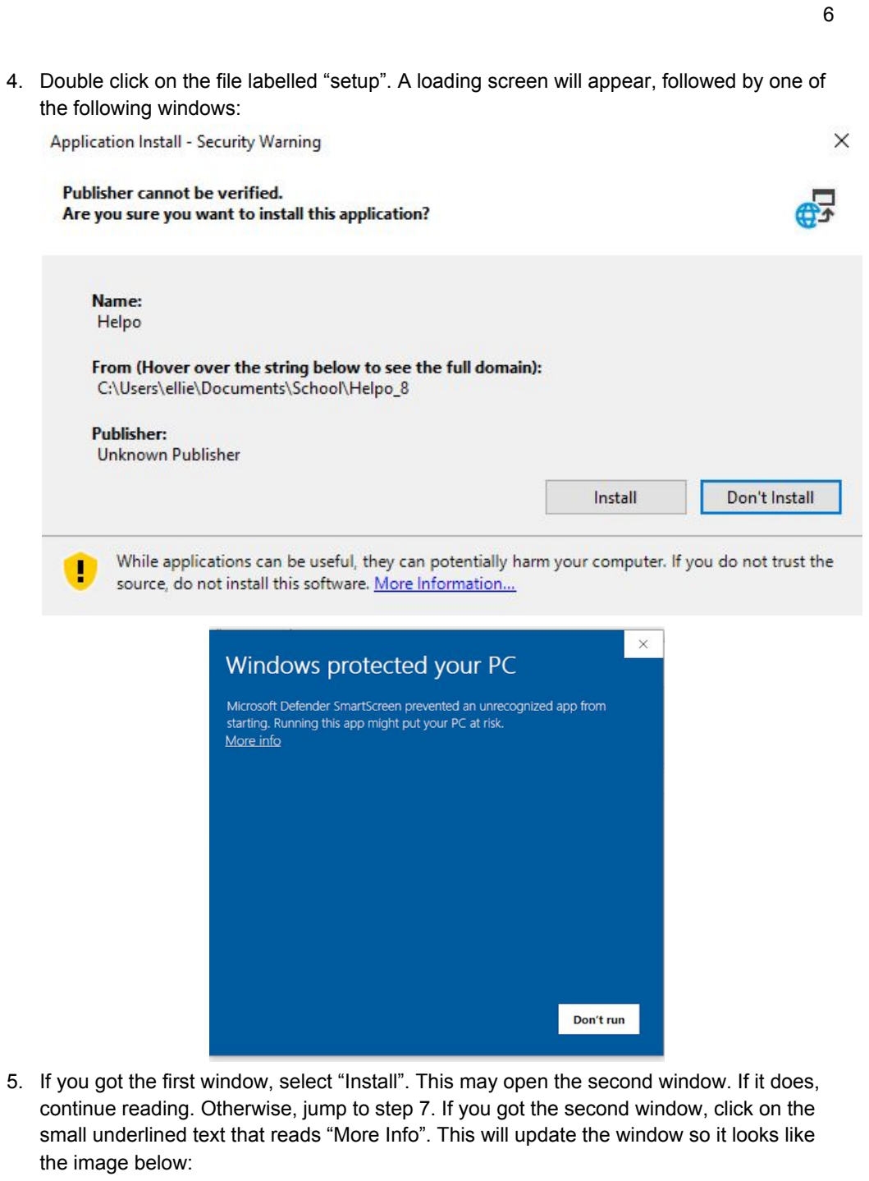
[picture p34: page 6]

4. Double click on the file labelled “setup”. A loading screen will appear, followed by one of the following windows:
5. If you got the first window, select “Install”. This may open the second window. If it does, continue reading. Otherwise, jump to step 7. If you got the second window, click on the small underlined text that reads “More Info”. This will update the window so it looks like the image below:

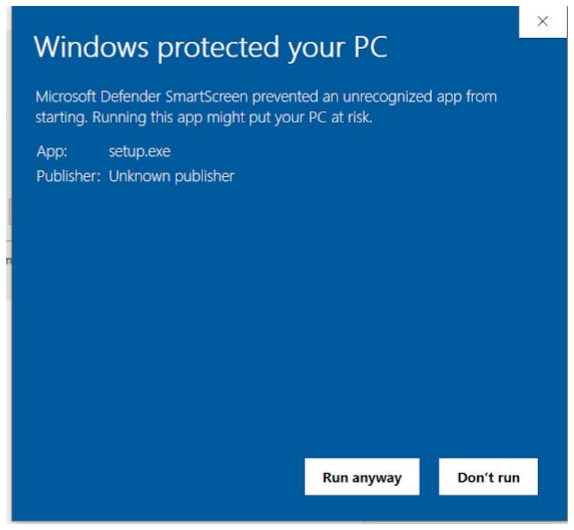
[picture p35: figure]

6. In this window, select “Run anyway”. A loading window will appear as the application installs. The application should then open automatically. See troubleshooting information below if any additional windows pop up.
7. Congratulations! Helpo is now installed and almost ready to run. The next step is to upload a profile so that Helpo knows what to do when you talk to it. In the top left corner of the application, find a button labelled “File”. Click on this, then find one named “Open Profile”. Click on this one as well. This will open a file tree. Remember that “Helpo.XML” file you downloaded? It’s now time to find that. On the left of the file navigator, find “This PC”. Navigate your file tree until you find the “Helpo.XML” file. Once there, select it with a left click and then press on open.
8. Helpo is now ready to take in a command! Test this out by pressing the “toggle microphone listening” button and saying “Thank you”. You should hear Helpo talk back with a nice robotic “You’re welcome”. If so, then Helpo is working and you are almost done. If not, then please see troubleshooting information below.
9. To make sure Helpo is always there and ready to help, it should be easy to access. For the final step in this installation, go to your desktop and right click. Navigate to “New” and then left click on the option near the top that reads “shortcuts”. This will open another file navigator. Navigate through the file tree until you get to where you originally saved your downloads. Double click through the “Helpo_8” folders until you get to the screen where you originally saw the “setup” file. This time, select the file named “Helpo”. Select “OK” in the file navigator and then “Next”. This will open a screen where you can name your shortcut. Leave it as “Helpo” and select “Finish”.

### 10. Color picker: In order to activate the Photoshop color picker using the key on the

keyboard, you will need to set up a custom shortcut in Photoshop. We also recommend choosing the “System” color picker for ease of use.
a. See the section in this document for making your own keyboard shortcuts
b. Set the color picker to your system default, rather than Photoshop’s:

i. Choose Edit > Preferences > General (Windows) or Photoshop > Preferences > General (Mac OS).
ii. | Choose the system Color Picker from the Color Picker menu, and click
| OK

Congratulations! You now have Helpo up and running on your computer. Next time you want to open the application, simply double tap on your shortcut and the application should start running!

## Troubleshooting installation

If you experience any of the following errors during installation, don’t worry! These are normal, since this is technically an unverified application.

- Something along the lines of Do you want this program to make changes to your computer?
- You have to be the system administrator to approve this. If you are, approve it. Otherwise contact your system administrator.
- “Could not find file...xml. Would you like to revert to default values?”
- This is fine, just click “Yes”

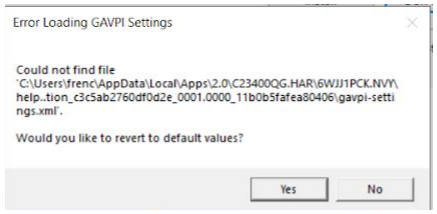
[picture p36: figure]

- Unable to reopen application after closing it
- Please go to the Task Manager (Ctrl+Shift+Esc) and find the process called “Helpo” or “GAVPI”

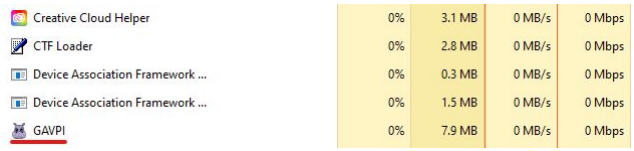
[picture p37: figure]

- Click this task, then click “End task” at the lower right corner of the window.
- If you still aren’t able to reopen Helpo, try restarting your computer.

- Helpo is not taking in your voice commands
- Make sure that you have a microphone attached to your computer. This can be done by going to your start menu at the bottom left of the screen and typing “Sound”. The sound settings menu will open. Make sure that you have a microphone available and that it works by testing with the “test microphone” bar. ■ Make sure that this bar moves when you talk and does not when you are silent. If the bar is constantly working, your room is too noisy and Helpo will have difficulty picking up commands. If this bar is not moving, your microphone is either disconnected, disabled, or hidden and cannot hear you. Make sure that this bar can move before continuing.
■ If the bar is moving but commands are still not working, ensure that all other programs using your microphone are closed. This could include internet chatting programs, video games, or web browsers.
- Look at the bottom of Helpo at the “Voice History” box.
■ If you are talking and nothing is appearing in this box, make sure that you have a profile loaded into the software and that it is reading “LISTENING” in the bottom left margin. You may have to load in a profile every time you open the application, so have it in an easily findable location. If it says “NOT LISTENING” select the “toggle microphone input” button and try speaking again.
■ If you are talking and question marks are appearing in the box, Helpo is taking in your words but cannot link it to any commands. Make sure you are speaking the correct command words. Test this out with simple commands like “Zoom In”, “Brush”, or “Thank you”. The more you talk to Helpo, the better it gets at interpreting your voice, so keep trying.
- If the above has not helped, try restarting the Helpo application fully by following the steps in the “Unable to reopen application after closing it” section of troubleshooting

# Using Helpo

## Introduction

The following section will be a quick overview of all of the features that Helpo uses. Helpo works by using voice commands already built into Photoshop. By building a “profile”, Helpo is given a list of command phrases to listen for. When it hears a command phrase, it will activate the control sequence associated with that command. For example, when the phrase “brush” is said, Helpo activates the control sequence associated with it and performs the actions in it; in this case, Key press B followed by speak action “new tool selected”. Let’s explore the Helpo software:

On the right of this document is the standard layout of the Helpo
software. At the top, we have three buttons: “File”, “Profile”, and
“Settings”. “File” is used to open new profiles into the software. Once uploaded, the “Profile” button is used to modify these existing profiles. We will be exploring this in a later section. The “Settings” button is primarily used by the GAVPI software, which Helpo is built on. It can be use to enable button-toggled listening, but this was simplified by the Helpo software. You should not have to use the “Settings” button.

The next section is our tool selection visible feedback. It contains 20 of the most common tools used in photoshop and their logos. These logos are used as visual feedback for the artist. Whenever a
command is made that activates one of these tools, it will turn blue, informing the artist that the tool has been selected.

The next section is our toggle buttons. Two buttons exist here, a “Toggle voice listening” and a “Toggle keyboard listening”. The voice listen button only becomes available once a profile is loaded in. When toggled off, the program is not listening, as seen in the bottom margin. Once a profile is loaded and commands can be made though, the button can be pressed and the margin will change to reading “LISTENING”. This means that any voice commands you now say will attempt to run through the software. The toggle keyboard button follows the same principle. Having it off will stop the 20 buttons above from becoming blue when a key sequence is pressed. When running
the software and making art, both buttons should be toggled on.

The final section in the software is the “voice history”, which simply

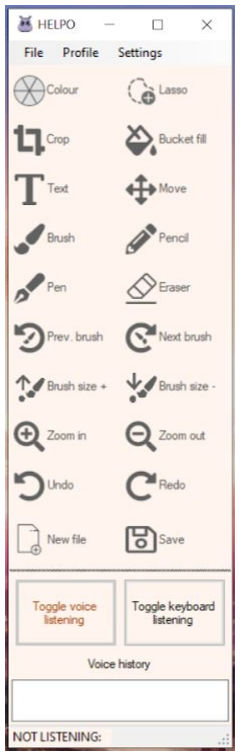
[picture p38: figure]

shows the last three commands that have been run through the software. Successful commands will show the command title and unsuccessful ones will be read as a “?”. This section is useful for seeing which command is being run on ones that sound very similar, like “Next” and “Text”.

## Using Helpo with Photoshop

Helpo is designed to be run in conjunction with Photoshop. We recommend having it open and visible with Photoshop, as seen in the image below:

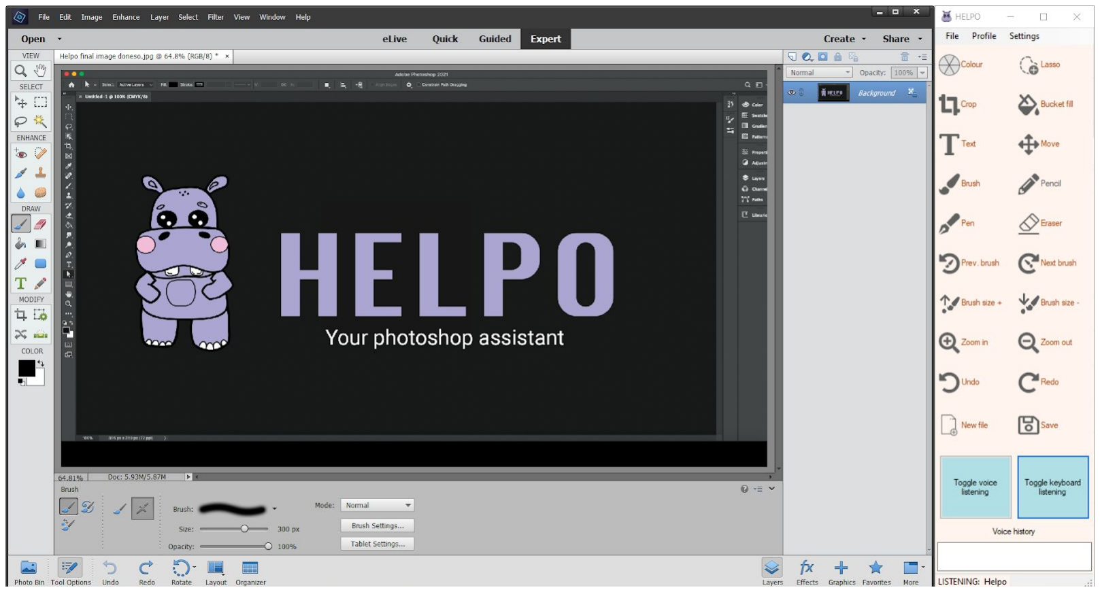
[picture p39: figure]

As it can be seen, a profile is open and listening, and both the “Toggle voice listening” and the “Toggle keyboard listening” buttons have been turned on. Now, art can be done in the main photoshop window but any commands can be seen in the side Helpo window. Note that with a Windows 10 operating system, the following can be set up quickly by opening both applications, dragging Helpo to the right edge of the screen, releasing, and selecting the photoshop application in the other box, and then dragging the separation line about three quarters of the way across the screen. Helpo should now be ready to help you create art!

### Making your own keyboard shortcuts

Photoshop has too many tools to give them all shortcuts. Maybe there is a tool you like though and wish you could access faster, and that's where these steps come in. Please note, to use the Color Menu command in Helpo, a custom keyboard shortcut must be set for the color menu and it must be keybound to the letter “n”.
1. Select the edit button in the top left of the photoshop menu bar
2. From the dropdown menu, select keyboard shortcuts
3. Find the “Set Menu” option and select it
4. Select “Set of shortcuts”
5. Find the shortcut you want to modify

6. Save the selected set of keyboard shortcuts.
If a certain keyboard shortcut already has a sequence attached to it, Photoshop will give you a warning. Either delete the existing shortcut or find a different keyset to use. The following website has a complete list of photoshop shortcuts available: (https://helpx.adobe.com/ca/photoshop/using/customizing-keyboard-shortcuts.html)

## Master list of possible commands

Helpo has a lot of powerful commands built into it. To use it, we need to know what our command phrases are. The entire list of commands can be found in Appendix A2. Now you’re set to use Helpo with Photoshop!
The remaining sections of this document outline optional customisation and a summary of how Helpo was built. If you only want to use Helpo, then feel free to ignore the rest of this information.

# Optional customisation

## Building your own profile

So, maybe you’ve found some commands that Helpo is not using. Maybe you’re interested in using the software to help with other tasks. Maybe you don’t like some of the command names and want to change them to something you would use more often. No matter the reason, this is the right section. Let’s start by exploring the “Profiles'' button in the GAVPI software.
To access this section, select “Profiles” and hit “New”. This will open the GAVPI profile builder. Any edits or creation you make will be done in the Events window. Let’s explore what each of these three windows mean.

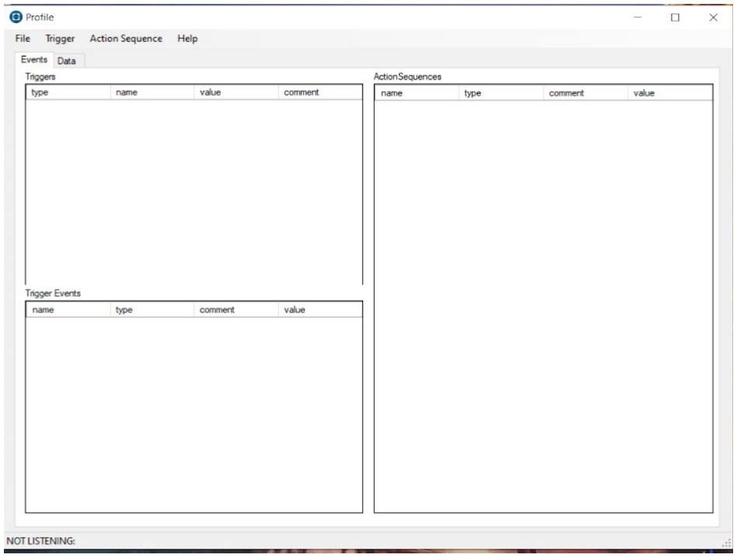
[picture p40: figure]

The “Triggers” window contains a master list of all of the commands built into your profile. These are the words you will speak to interact with the software. The name of a trigger and its
command phrase should match for ease and simplicity.

The “Trigger Events” window details the sequence of events that will follow when a command is spoken. To view this information, left click on a trigger in the “Triggers” window. The information in the “Trigger Events” window should update automatically, showing the sequence of actions that will be performed from top to bottom.

The “Action Sequences” window is where all the magic happens. Any action you build will be placed in this window where it can be added to triggers so that your commands actually do something! An example of an action sequence would be “Pressing b”. This action involves two internal commands, “B Key Down” and “B Key Up”. The action of “Pressing b” could then be added to multiple triggers, like “brush” and “type b”. Both triggers use the same action sequence, but “brush” is followed by a “complete” action to confirm that a tool has been selected, while the “type b” command does not. The “complete” action in “brush” trigger is its own separate action, but the combination can be seen in the “Trigger Events” window. It is useful to break your triggers into individual action sequences for this reason, so that they can be reused and you can save time. An example of this in the Helpo software can be seen in the following image:

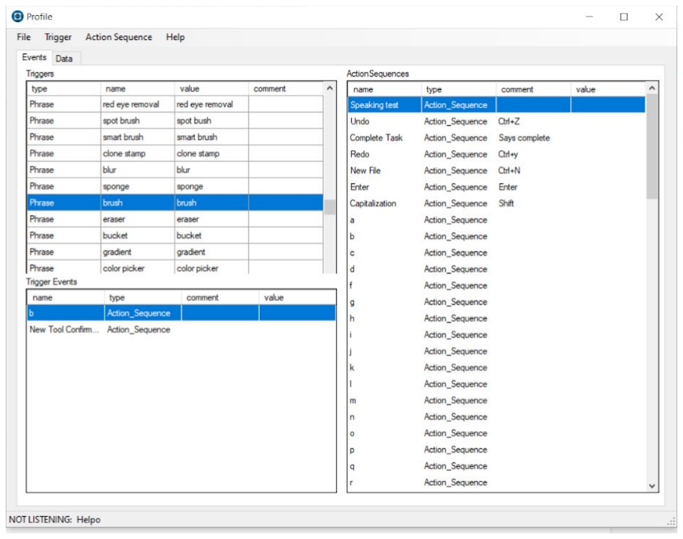
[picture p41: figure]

Now let’s have a step-by-step look at how to make an entire profile.
1. Decide on what your trigger will be.
a. For the purpose of this example, we are going to write a command that will save our file in photoshop.
2. Figure out all of the actions in your trigger
a. For a “Save File”, we need to complete the save and then give audio feedback confirming the save
3. Figure out the necessary keyboard shortcuts to complete your actions.
a. To save a file in photoshop, we must hold the “control” key and press the “s” key. A list of common keyboard shortcuts for photoshop and other applications can be found online. To build an audio feedback, we can use GAVPI’s “speak” function
4. Create your action sequences
a. In the top menu bar, find the button labelled “Action Sequence” and select “New”. This will open up a new menu, as seen in the following image:

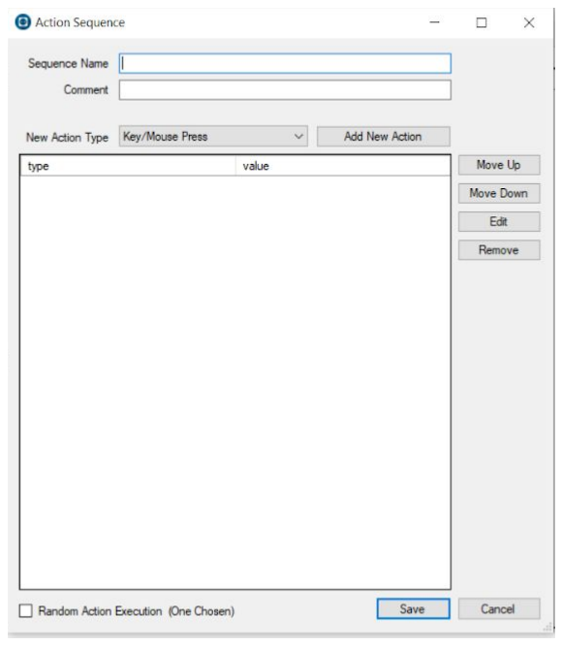
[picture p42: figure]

b. Type out a name for your sequence and write any additional comments. In this example, the sequence name will be “Save File” and the comment will be “Ctrl+S”.
c. Figure out what kind of action you will need in the drop down menu that reads “New Action Type”. Only worry about the “Key/Mouse press”, “Timing”, and “Speak Action” options. These will let you add keyboard presses, delays, and spoken words respectively. One figured out, hit the “Add New Action” button.
d. This will open a new window again. This is where you will select what kind of key press you want (press vs. hold), how long of a delay you want, or what words you want spoken. Select the information you want and press “Add”. For this example, see the following screenshot:

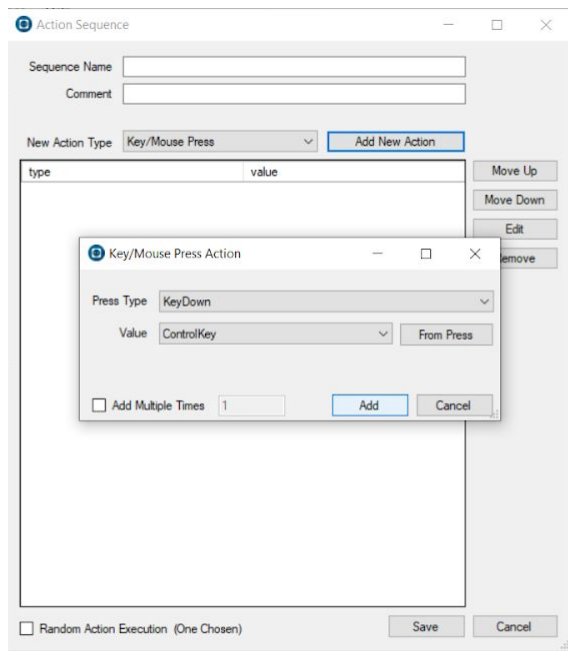
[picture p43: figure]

e. Repeat the previous step until every single command you need in the sequence is completed. For this example, we need a key press down Control, a Key press S, and a key press up (release) Control, since the S key needs to be hit while Control is being held. See the screenshot below.

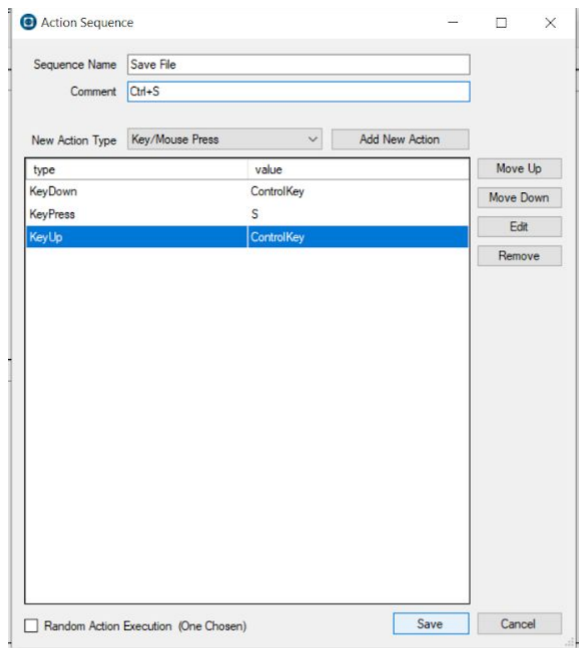
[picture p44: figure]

f. These commands can be reorganized with the “Move up” and “Move down” buttons on the right. Make sure your sequence is correct from top to bottom. Once satisfied, press the “Save button”
g. Repeat this process for every single action sequence in your trigger. An example of a speak trigger is shown below, which uses a timing delay to make the sequence feel a little bit more natural
5. Create your Trigger

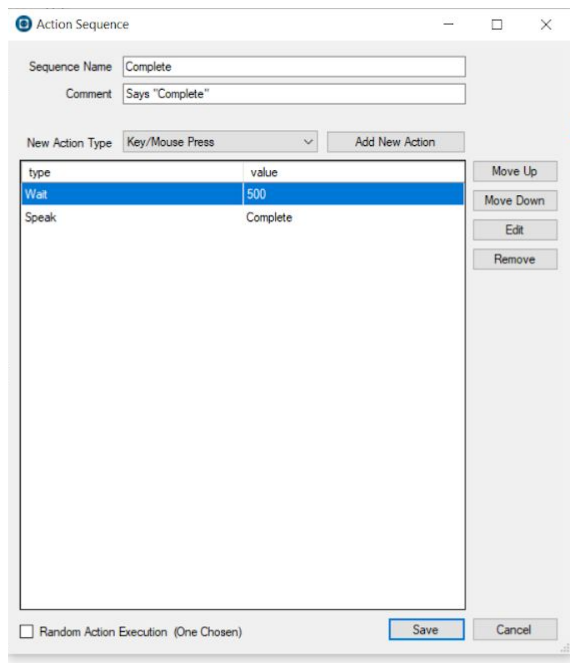
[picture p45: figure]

a. In the menu bar at the top, select “Trigger”, then select “New”, then select phrase. This will open a new menu. Fill in the Trigger Name and Command word

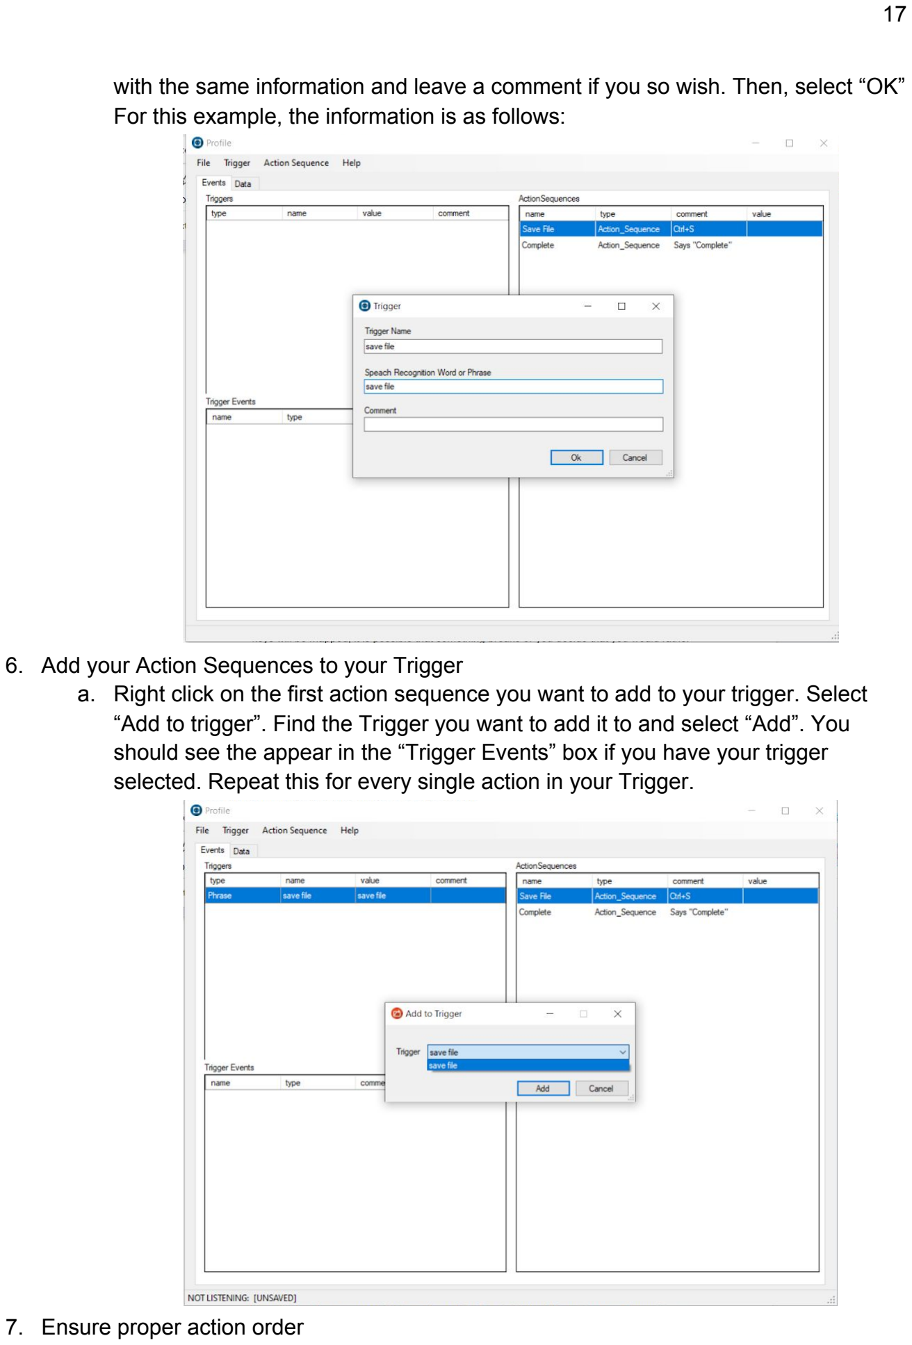
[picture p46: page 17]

with the same information and leave a comment if you so wish. Then, select “OK” For this example, the information is as follows:

6. Add your Action Sequences to your Trigger
a. Right click on the first action sequence you want to add to your trigger. Select “Add to trigger”. Find the Trigger you want to add it to and select “Add”. You should see the appear in the “Trigger Events” box if you have your trigger selected. Repeat this for every single action in your Trigger.
7. Ensure proper action order a. Select your trigger in the “Triggers” window and look at the “Trigger Events” window. Ensure that your sequence is what you want from top to bottom.

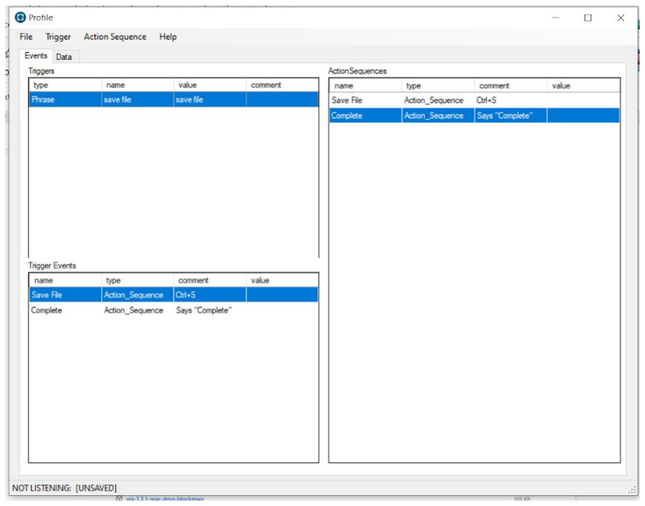
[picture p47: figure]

8. Repeat steps 1 through 7 for every single trigger you want to include in your new profile
9. Once finalized, save your profile by going to “File” and selecting “Save as”. Make sure to name this file something you would recognize and place it in a folder you can find again. Now, you can upload this new profile into the Helpo software and use it to map any voice command to a keyboard shortcut for anything.
This may seem like a lot of steps, but once you get practice at it, creating profiles is easy. Just know what you want and then follow the steps to do it. Some examples of profiles you might want are for other modeling applications, like Blender, or for editing softwares like FinalCut. You can also use this to map voice to video game controls, which could put a fun spin on how you play. Anything that uses a keyboard can use your voice too!

## Installing VIA for Custom Keyboard Mapping

The following section is specifically for the physical keyboard that comes with Helpo. While the keys will be mapped, it is possible that something breaks or you decide that you would rather have different keys mapped. This can be quickly fixed with the VIA custom mapping software.
1. Visit caniusevia.com to and click into the download page. This should lead you to a github repository.

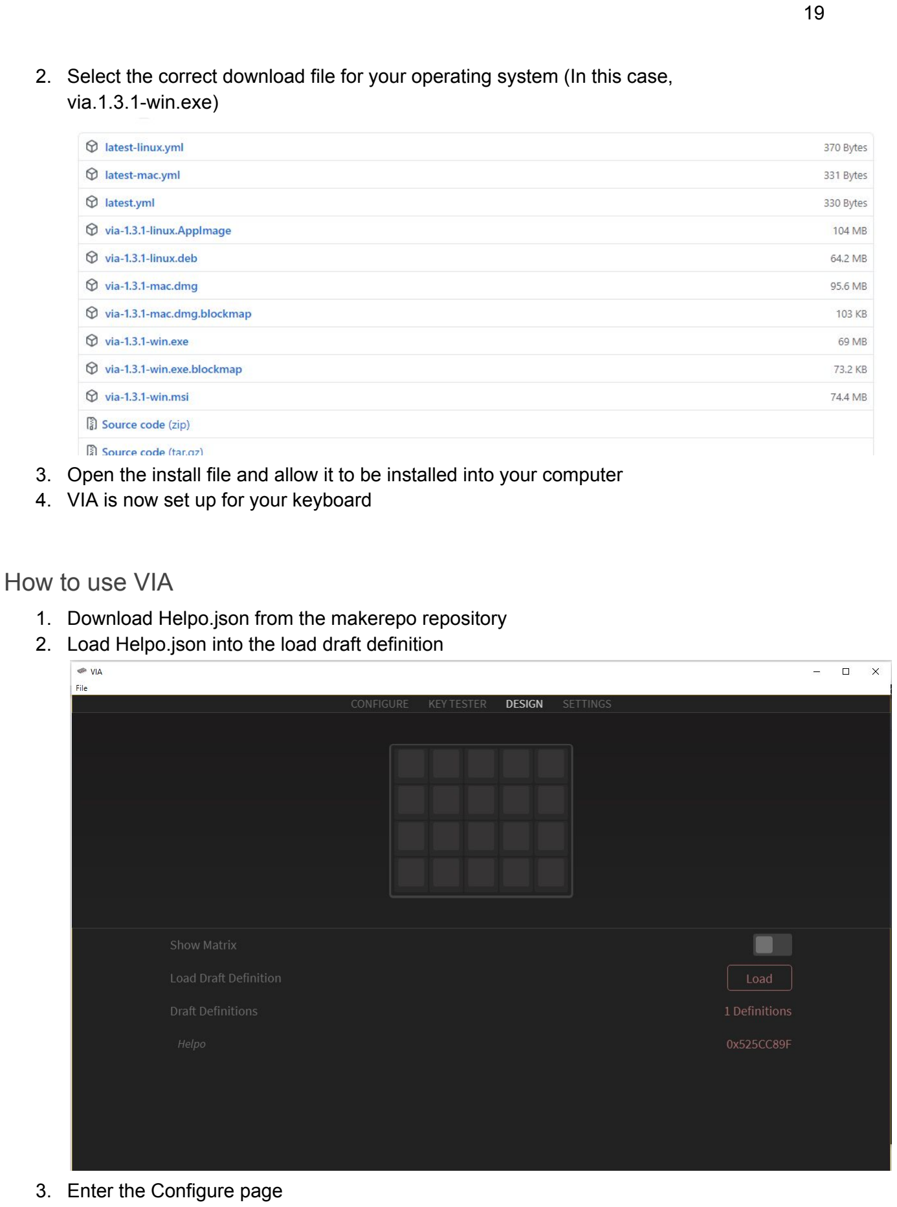
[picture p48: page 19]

2. Select the correct download file for your operating system (In this case, via.1.3.1-win.exe)
3. Open the install file and allow it to be installed into your computer
4. VIA is now set up for your keyboard

### How to use VIA

1. Download Helpo.json from the makerepo repository
2. Load Helpo.json into the load draft definition
3. Enter the Configure page

4. Select the key that you want to change on the top half of the software
5. Select what function you want that key to perform on the bottom half of the software
6. Once you are done with changing the keymaps you can close VIA at any time.

# Technical summary

## Software prototyping summary

The software was built as a Windows Forms application. It was important that we made this application run at a fairly low-level to the operating system so that it could detect keypress signals. This is not possible with more high-level languages, such as JavaScript (which is what we originally wanted).
The software was built on top of the pre-existing GAVPI application, which is an open source project. You can find the original GitHub repository here: https://github.com/baykovr/AVPI/releases/tag/17.03.15. We made a number of modifications to this code and removed unnecessary functionality, so we recommend that you use our source code from the MakerRepo for this project (https://makerepo.com/Frenchfrie/helpo-your-photoshop-assistant).
To open our project, download the GAVPI.zip file from the MakerRepo. Unzip (extract) the files. Open the “GAVPI’ folder, the contents should look like this:

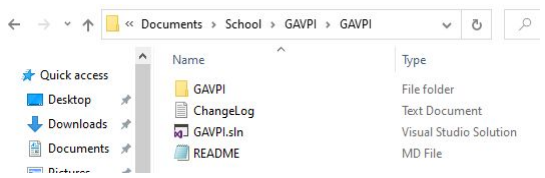
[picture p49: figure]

Visual Studio 2019 is the best IDE for Windows Forms applications. If you haven’t installed it already, follow this link to download it: https://visualstudio.microsoft.com/downloads/. It is important that you use Visual Studio 2019 and not Visual Studio 2020, as they are very different IDEs. Once you have completed the installation, open the GAVPI.sln file in Visual

Studio. You can press the “Start” button at the top of the screen to run the solution.

### Software troubleshooting

It is important that you run this solution as an administrator. If you are not logged into the system administrator profile for your computer, you may get an error message that prompts you to sign in an administrator and restart VSCode. If you follow the steps on the screen, the code should then run.
If at any time you get a “Build failed” message or are unable to run the solution without any error messages shown, you will just need to quit Visual Studio and restart it.

## Hardware prototyping summary

The keycaps were designed in Fusion 360 by extruding the symbols found in the table below into the keys. Once designed they were 3D printed and placed onto the keyboard. The file containing all of our keys can be found in the Makerrepo. Each row of keys is shaped slightly differently for ergonomics.

Pencil

Pen

Eraser

Zoom In

Zoom Out

Brush

Brush Size Up

Brush Size Down

Next Brush

Previous Brush

Pick Colour

## Health and Safety Guidelines

The keyboard is soldered together using solder. Solder may or may not contain lead. Do not open up the keyboard and touch any of the solder joints.

## Hardware Troubleshooting

- If keys are not working
- Check using the VIA software if keyboard inputs are being registered, then check if the corresponding key is mapped to anything. If the key is not mapped to anything, map it to the desired key commands
- If the keyboard is not being picked up by the computer

Move

Lasso

Crop

Bucket

Text

New File

Save File

Undo

Redo

- Try switching cables and check if the connection between the keyboard and computer is secure.
- If the computer picks up ATMEGA32A:
- Refer to
https://www.youtube.com/watch?v=VR53Wo9Z960&ab_channel=MechMerlin and flash axolstudio_helpo_via.hex onto the board

### Hardware Alteration

In the event that the schematics are to be changed, it can be referenced to the gerber output files. The location of the footprints can be changed however the routing of the traces will have to be redone. The diodes are primarily grouped on the top left, whereas the MCU takes up most of the space on the top right.
Below features the schematic in the PCB drawer tool in KiCad.

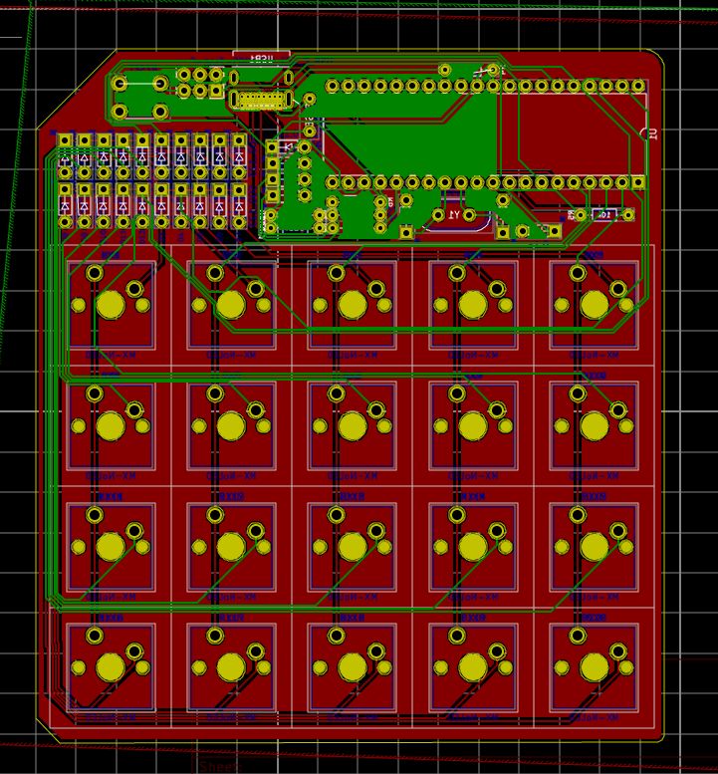
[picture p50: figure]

# Conclusions and Recommendations for Future Work

The development of Helpo was nothing short of difficult. Due to the restrictions of COVID-19, the team had to learn how to collaborate efficiently in various remote locations. Thanks to very detailed scheduling and a winning team dynamic, Helpo has become a product that is beneficial for everyone, accomplishing more than it was required to. With the help of multiple deliverables that were required to be completed on a weekly basis, we all understood as a team how crucial it was to stay organized within our personal schedules as well. To accommodate for that, we all agreed on a specific time to meet up every week to discuss what objectives needed to be completed for the present week. As a team, we learned to work to each individual’s strengths which became easier to execute with time. By handing out tasks that were better suited for each respective member, this sped up the development process and increased overall productivity within the team. However, the journey was not as smooth as it seems, throughout the semester we faced multiple issues ranging from the software to hardware when trying to create Helpo. Initially, we had trouble finding the right software framework that could function smoothly with Photoshop’s interface, and found ourselves switching multiple times. We also faced some delays in trying to send our keyboard from one member who made the keyboard and another with the custom keycaps for our client. Through all the hardships that we faced as a team throughout the semester, Helpo was a result of everyone’s efforts which shows in the quality of the product.

For more information regarding the development of Helpo, visit our Helpo Repository (https://makerepo.com/Frenchfrie/helpo-your-photoshop-assistant) at makerepo.com. For any additional questions, feel free to contact any one of the following email addresses:
- Austin Wu
- Ben Saulnier
- Callum French
- Ellie Rumsey
- Matt Yakubu

# Appendices

## A1. The Helpo keyboard Bill of Materials (BOM)

Comprehensive Bill of materials (BOM) for the keyboard prototype

Component | Description | Quantity | Price ($)
ATMEGA32A-PU | Microchip | 1 | 4.67
1-2199299-5 | DIP Socket | 1 | 1.15
512-1N4148TR | Semiconductor | Number of switches | 0.07*20
TZX3V6A-TR | Semiconductor | 2 | 0.27
MF-R050 | Circuit protector | 1 | 0.46
603-CFR-12JR-52-75R | Carbon-Film resistor | 2 | 0.14
MFR-12FTF52-1K5 | Resistor | 2 | 0.19
MFR-12FTF52-10K | Resistor | 1 | 0.19
UMT1H4R7MDD | Capacitor | 1 | 0.28
RDER71H104K0M1H03A | Capacitor | 2 | 0.41
RCE5C2A220J0A2H03B | Capacitor | 2 | 0.64

## A2. Comprehensive list of voice commands in the Helpo profile

ABL-16.000MHz-B4Y | Timing crystal | 1 | 0.45
MJTP1230A | Tactile switch | 2 | 0.26
LTL-4222 | LED light | 1 | 0.16
68602-406HLF | Wire housing | 1 | 0.39
USB4085-GF-A | USB receptacle | 1 | 1.3
PCB | Printed Circuit Board | 1 | 7
Switches | Switches | Number of switches | 0.2*20
Keycaps | Keycaps | Number of switches | 0.3*20
TOTAL: | | | $ 29.6
Command Phrase | Command Actions | Keyboard Shortcuts
Undo | Undoes the last action | Ctrl+z
Redo | Redoes the Undone action | Ctrl+y
New File | Opens a new file | Ctrl+n
Next | Tab’s to the next option in a menu | Tab
Enter | Submits a menu | Enter
Type a, Type B, etc... | Types a letter of the alphabet, a through z | Press *letter*
Type Capital A, | Types a capitalized letter of the alphabet, A | Hold Shift, press

Type Capital B, etc.. | through Z. | *letter*, Unhold Shift
Type Space, Type period, etc.. | Can be used to type different commands, like spacebar, period, dash, and underscore | Press *symbol*
Type 1, 2, etc.. | Type any numbers | Press *keypad*
Go up, Go right, etc.. | Hits the arrow keys in directions up, down riht, left. | Press *directional arrow*
Zoom | Selects the Zoom tool | Press z
Hand | Selects the Hand tool | Press h
Move | Selects the Move tool | Press v
Lasso | Selects the Lasso tool | Press l
Select | Selects the Select (Marquee) tool | Press m
Quick Select | Selects the Quick Select tool | Press a
Red Eye Removal | Selects the Red Eye Removal tool | Press y
Spot Brush | Selects the Spot Brush tool | Press j
Smart Brush | Selects the Smart Brush tool | Press f
Clone Stamp | Selects the Clone Stamp tool | Press s
Blur | Selects the Blur tool | Press r
Sponge | Selects the Sponge tool | Press o
Brush | Selects the Brush tool | Press b
Eraser | Selects the Eraser tool | Press e
Bucket | Selects the Bucket tool | Press k
Gradient | Selects the Gradient tool | Press g
Color picker | Selects the color picker tool. Used to be called the “eyedropper” | Press i
Color Menu | Opens the color menu | Press n (must be set up manually)
Pen | Selects the Pen tool | Press p
Pencil | Selects the Pencil tool | Press b x2

Text | Opens the Text tool | Press t
Crop | Selects the Crop tool | Press c
Open | Open’s the “Open” menu in photoshop | Ctrl+o
Close | Closes a file in photoshop | Ctrl+w
Close all | Closes everything in photoshop | Alt+Ctrl+w
Save as | Opens the save menu to save a file | Alt+Ctrl+s
Save | Saves the active file | Ctrl+s
Print | Opens the print menu | Ctrl+p
New Layer | Creates a new layer | Shift+Ctrl+n
Merge layers | Merges the visible layers | Shift+Ctrl+e
Select all | Selects everything in a layer | Ctrl+a
Deselect | Deselects everything | Ctrl+d
Invert Selection | Inverts the selected pixels | Shift+Ctrl+i
Refine Edge | Refines the selected edge. Useful for smoothing out curves and blending edges. | Alt+Ctrl+r
Zoom in, Zoom out | Zooms the camera in or out | Ctrl++, Ctrl+-
Fit to screen | Fit’s the canvas to the screen | Ctrl+0
Toggle rulers | Toggles rulers to work as guides | Ctrl+r
Cut | Cuts the selected pixels | Ctrl+x
Copy | Copies the selected pixels | Ctrl+c
Paste | Pastes the selected pixels | Ctrl+v
Left Click | Performs a left mouse click | Left Mouse button
Right Click | Performs a right mouse click | Right Mouse button
Decrease Size, Increase Size | Decreases or increases the brush size on a selected brush | Press [, Press ]
Decrease Hardness, Increase Hardness | Decreases or increases the hardness of a brush. This is usually useful for airbrushing or for pencils | Press {, Press }

Previous Brush, Next Brush | Changes brush selection one at a time | Press ,(comma), Press .(period)
First Brush, Last Brush | Jumps to the first or the last brush option in the brushes menu | Press <, Press >
Access menu, Access file, etc... | Accesses any of the more specific files in the top bar of photoshop. Useful for accessing any of the stronger photoshop tools. Options include Menu, File, Edit, Enhance, Layer, Select, Filter, View, Window, Help, and Image. Navigate the menu using the “go __” commands and “enter” | Alt, right directional arrow for varying amounts, down directional arrow
Toggle toolbars | Toggles the toolbars on and off | Tab
Hello World | Speaks “Hello” and “Goodbye” | No keyboard input
Thank you | Helpo says “You’re Welcome” | No keyboard input
